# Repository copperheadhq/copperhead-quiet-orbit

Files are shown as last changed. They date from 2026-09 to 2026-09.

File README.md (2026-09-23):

# Quiet Orbit QO-R1

A USB-C powered desk ornament: four amber LEDs at the corners of a 40 mm square, each on its
own hardware-PWM channel of an ATtiny84A, fading independently on four phases. 57 × 57 mm,
two layers, no data, no PD, no radio, no battery, no controls.

> ## ⚠ This board has never been built
>
> No PCB has been fabricated from these files. Nothing has been powered on. The firmware has
> never been compiled, because no AVR toolchain was available where it was written, and it has
> never run on hardware. Every manufacturer part number in the BOM is marked **UNVERIFIED** by its own
> author, and at least one fitted part is known to be the wrong choice.
>
> The files pass ERC and DRC. That means the copper is consistent with the schematic and with
> a set of design rules. It is not evidence that the circuit works.
>
> **Do not order this board expecting a working lamp.** Order it to look at, to fork, or to
> fix.

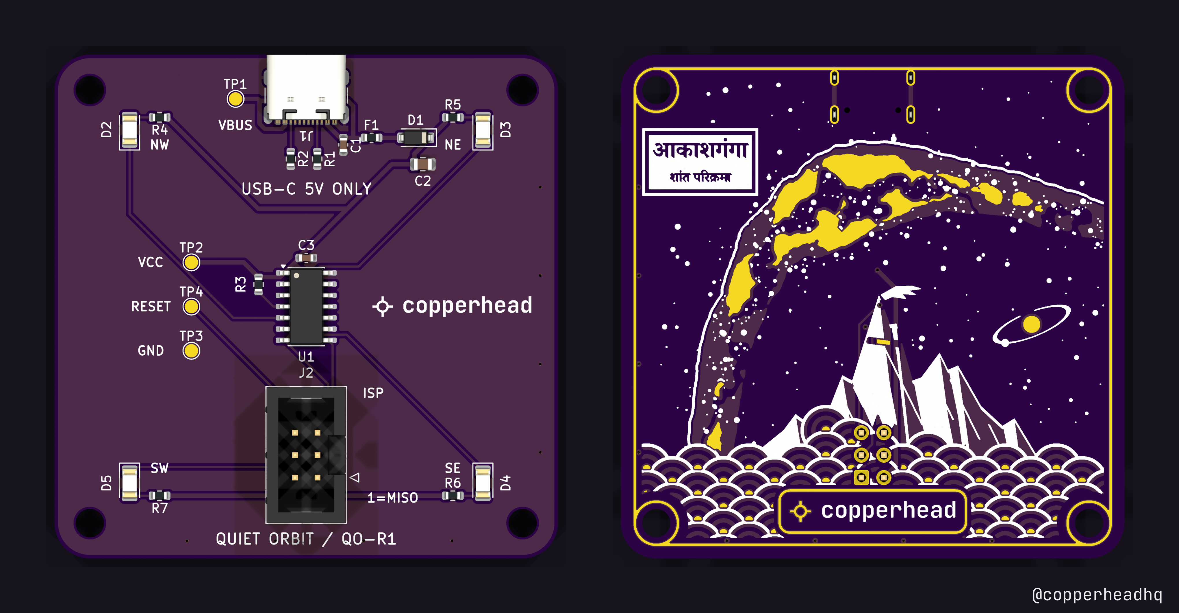
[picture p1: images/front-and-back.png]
The 57 mm board, front and back (a render, not a photograph)


Quick facts: [docs/QO-R1-summary.pdf](docs/QO-R1-summary.pdf). Everything: [docs/QO-R1-reference.pdf](docs/QO-R1-reference.pdf).

## Background

On 21 September 2026, Paras Chopra [posted](https://x.com/paraschopra/status/2101906787050115492)
that he had asked an AI model he calls Astra to design a piece of hardware for itself. It chose
four softly blinking lights powered by USB, and produced a PCB, a casing and an email to a
manufacturer.

The same day we gave that post to [copperhead](https://x.com/copperheadhq) as a brief and
[shared the result](https://x.com/animeshsingh38/status/2102001126682042727). This repository is
that build, with its source files. It is an independent design that started from the public post. No files, images or schematics
from the original project are used here.

## The circuit

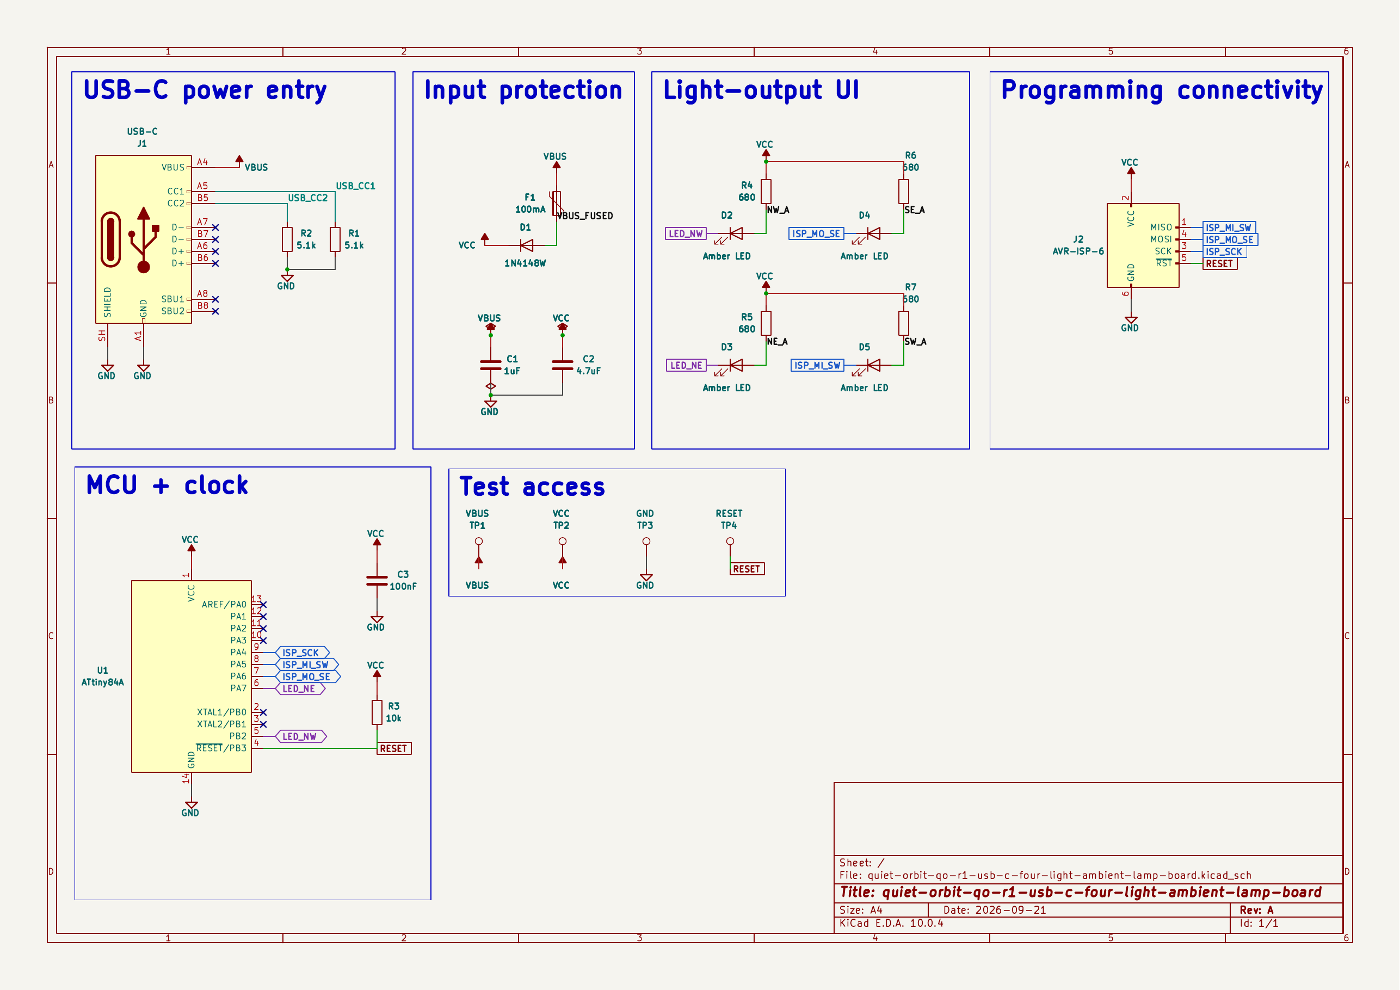
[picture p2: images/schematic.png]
Schematic


Full sheet as [PDF](docs/schematic.pdf) or [SVG](docs/schematic.svg). Source of truth is
`hardware/*.kicad_sch`. The exports are generated from it.

## Layout of this repository

```text
hardware/           KiCad 10 project: schematic, 57 × 57 mm board, design rules,
                    project footprint and symbol libraries
  variant-milkyway/ alternative back with Milky Way artwork in copper, mask and silk
firmware/           AVR-GCC, ATtiny84A, two 8-bit timers driving four PWM channels
docs/               summary and reference PDFs, specification, subsystems, pinout, BOM,
                    design decisions, changelog, and the schematic as PDF and SVG
fab/                gerbers, drill, BOM and CPL (read the warning in that folder)
images/             renders of the board, not photographs
3d/                 STEP, GLB and STL models, including one for an enclosure designer
LICENSES/           full text of the three licences below
```

## Building it

**Hardware.** Open `hardware/*.kicad_pro` in KiCad 10.0.4 or newer. The project carries its own
symbol cache and footprint libraries, so it opens standalone.

**Firmware.** Needs `avr-gcc` and `avr-libc`:

```bash
make -C firmware        # produces quiet-orbit-qo-r1.hex for attiny84 at F_CPU=8000000UL
```

This has never been run. If it does not compile, please send a patch.

Flash through J2 with any AVR ISP programmer. The ATtiny84A arrives blank and runs on its
internal 8 MHz RC oscillator. There is no crystal and no regulator. If your part ships with the
clock divided by 8, change that fuse; nothing else needs changing.

## Licence

Three licences, by file type:

| What | Licence |
|---|---|
| Hardware: everything under `hardware/`, `fab/` and `3d/` | **CERN-OHL-S-2.0** (strongly reciprocal) |
| Software: `firmware/` | **GPL-3.0-only** |
| Documentation and images: `docs/`, `images/`, `README.md` | **CC-BY-4.0** |

Full texts are in [`LICENSES/`](LICENSES/). In short: you may make, modify, sell and fabricate
this, and if you distribute a modified board or modified firmware you must publish your sources
under the same terms. See [`LICENSE`](LICENSE) for the per-directory statement.

**Trademarks are not licensed.** The copperhead word mark and the snake lockup that appear on
the silkscreen are trademarks; the licences above cover the design, not the marks. If you
fabricate a modified board, remove them from the silkscreen.

**No warranty.** This is an unbuilt, unverified design. CERN-OHL-S-2.0 sections 8 and 9 apply:
no warranty, no liability. If you fabricate it, that decision is yours.

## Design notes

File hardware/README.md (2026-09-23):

# Hardware

KiCad 10 project for the Quiet Orbit QO-R1. Open `*.kicad_pro`.

This board has never been fabricated. The series diode D1 (1N4148W) is the wrong part for the
power path; a 1 A Schottky in the same SOD-123 footprint is the better fit.

| File | What |
|---|---|
| `*.kicad_sch` | schematic |
| | *(readable exports: `docs/schematic.pdf`, `docs/schematic.svg`)* |
| `*.kicad_pcb` | 57 × 57 mm, 2 layers |
| `*.kicad_dru` | custom design rules, described below |
| `*.kicad_pro` | project settings, including the rule set used for DRC |
| `schematic.intent.json` | the machine-readable intent the schematic was generated from |
| `sym-lib-table`, `sym-lib-cache/` | project symbols, so the project opens standalone |
| `libs/footprints/` | project footprint libraries, from the KiCad standard set |
| `variant-milkyway/` | alternative back with copper artwork |

## Design rules

Our own conservative set, not any named fab's: clearance 0.2 mm, track 0.25 mm signal and 0.5 mm on
the power rails, via 0.65 / 0.3 mm, copper to edge 0.4 mm, hole clearance 0.25 mm, silk text at
least 1.0 mm. No KiCad severity is changed from default and there are no DRC exclusions.

One scoped rule is in the `.kicad_dru`: hole clearance 0.19 mm between J1 and itself. The
USB-C receptacle's stock land pattern puts its GND pads 0.194 mm from its own locating-peg
holes, which is four errors on any board using that footprint at the board-wide 0.25 mm. The
board-wide rule is untouched. A fab with a hard 0.2 mm NPTH-to-copper limit will query it.

Every two-pad part also carries a thin no-track rule area across its pad gap. This was added
after the autorouter put a track between the pads of an 0603. That passed DRC but is poor
practice.

## Geometry

57 × 57 mm. LED optical centres on a board-centred 40 mm square (NW, NE, SE, SW). Four M3
NPTH holes, each centre 4 mm from both adjacent edges. USB-C centred on one edge and flush
with it. All populated parts on the top side.

57 mm is close to the geometric floor for this brief: at 56.5 mm the LED and M3 courtyards are
0.13 mm apart, and at 56.0 mm they overlap. Going smaller means moving the mounting holes
inside the LED square or abandoning the 40 mm pitch.

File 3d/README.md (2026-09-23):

# 3D models

Exported with `kicad-cli` from the 57 mm board. Component bodies are generic KiCad library
models, not the exact manufacturer parts. Use them for fit, not for tolerance.

| File | For |
|---|---|
| `quiet-orbit-57mm.step` | full model: tracks, pads, zones, silkscreen and mask |
| `quiet-orbit-57mm-mechanical.step` | board and component bodies only. Give this one to an enclosure designer |
| `quiet-orbit-57mm.glb` | the full model for a web or Blender viewer |
| `quiet-orbit-57mm-board-only.stl` | bare outline with holes, for a fit-check print |

The board is designed against an 80 × 80 × 25 mm enclosure with four light windows over the
LED positions. Note the 0.47 mm gap between the LED and M3 hole courtyards at each corner: a
baffle or light pipe has to share that corner with a screw head.

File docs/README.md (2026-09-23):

# Documentation

The design documents, published as they were written alongside the schematic.

| File | What |
|---|---|
| `QO-R1-summary.pdf` | two-page summary: key figures, LED channels, BOM, checks before ordering |
| `QO-R1-reference.pdf` | full design reference: requirements, circuit, pinout, BOM, power budget, firmware, PCB, fab outputs, status |
| `SPEC.md` | the product specification, with normative requirements and every assumption marked |
| `SUBSYSTEMS.md` | power architecture, LED drive, MCU and programming |
| `PINOUT.md` | the ATtiny84A pin map, and the source of `firmware/pins.h` |
| `BOM.md` | bill of materials, with a rationale per line. Every part number is marked UNVERIFIED |
| `LAYOUT.md` | how the 57 mm board is laid out |
| `DECISIONS.md` | design decisions with reasons, in the order they were made |
| `CHANGELOG.md` | one entry per design stage |
| `schematic.pdf`, `schematic.svg` | the schematic sheet, exported from `hardware/*.kicad_sch` with `kicad-cli` 10.0.4, text stroke weight increased for print and projection. Regenerate rather than edit |

Two caveats on reading them:

- `DECISIONS.md` and `CHANGELOG.md` sometimes reference files that are not in this repository:
  an `outputs/` directory, an `openspec/` workspace and a first-draft 70 mm `LAYOUT.md`. The `LAYOUT.md` here
  is a replacement describing the board this repository actually contains.
- `DECISIONS.md` records the choices as made at the time, including some later found wrong.
  The choice of a 1N4148W as the reverse-blocking diode is one of them; fit a Schottky instead.

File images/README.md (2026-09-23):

# Images

These are renders, not photographs. No board has been made. They come from KiCad's raytracer
using generic 3D models from the standard library, not the exact manufacturer parts.

| Files | View |
|---|---|
| `01-top.png`, `02-bottom.png` | orthographic |
| `03-`, `04-` | perspective from the ISP side |
| `05-`, `06-` | perspective from the USB side |
| `07-back-iso.png` | underside |
| `08-closeup-usb-input.png` | the input chain: connector, bulk cap, fuse, diode |
| `09-closeup-mcu-isp.png` | MCU, bypass, RESET pull-up and ISP header |
| `front.png`, `back.png`, `back-angle.png` | the Milky Way variant, purple mask and ENIG |
| `bare-top.png`, `bare-bottom.png` | the bare board with no parts fitted: pads, tracks, silkscreen and mask as a fab would deliver it |
| `bare-milkyway-back.png` | the Milky Way variant's back, bare, in purple mask with ENIG gold |
| `schematic.png` | the schematic sheet as KiCad plots it, with border, zone markers and title block. Same sheet as `docs/schematic.pdf` |

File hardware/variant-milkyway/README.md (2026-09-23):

# Milky Way variant

The same circuit and the same placement, with the back of the board turned into a picture: the
Milky Way arching over a mountain, built from three finishes a fab can produce:
copper with a mask opening (gold, on ENIG), copper under mask (purple) and bare laminate
(dark purple), plus silkscreen for the stars.

`*.kicad_pcb` and `*.kicad_pro` here replace the two files of the same name one directory up.
Everything else in the project (schematic, rules, libraries) is shared.

Differences from the plain board:

- 4 mm rounded corners.
- No back GND pour. The artwork needs bare laminate for its dark sky. The artwork's gold
  frame, including eyelets around the M3 holes, becomes the GND ring instead, because the
  USB-C receptacle reaches ground partly through its shell stakes and that pour.
- The artwork's copper is floating polygons with no net, cut back from every pad, via, track
  and hole. Large areas of intentionally floating exposed copper will look like an error to a
  fab's reviewer. Say so on the order.
- Requires ENIG, not HASL. HASL would tin the exposed copper and the picture would be lost.

DRC at all severities with schematic parity after the artwork was applied: 0 / 0 / 0.

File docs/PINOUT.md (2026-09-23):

# Quiet Orbit QO-R1 Pinout

This table is authoritative for schematic-stage signal assignment. Every unused signal pin is explicitly marked NC in `schematic.intent.json`.

| Ref | Pin | Net | Function | Rationale |
|---|---:|---|---|---|
| U1 | 1 | VCC | Protected 5 V supply | Direct protected-VBUS architecture requires no regulator. |
| U1 | 2 | NC | PB0 / XTAL1 unused | Internal 8 MHz RC clock eliminates an external clock connection. |
| U1 | 3 | NC | PB1 / XTAL2 unused | Internal 8 MHz RC clock eliminates an external clock connection. |
| U1 | 4 | RESET | Active-low reset / PB3 | Dedicated reset supports reliable AVR ISP. |
| U1 | 5 | LED_NW | PB2 / OC0A hardware PWM | Dedicated PWM sinks the NW LED channel. |
| U1 | 6 | LED_NE | PA7 / OC0B hardware PWM | Dedicated PWM sinks the NE LED channel. |
| U1 | 7 | ISP_MO_SE | PA6 / MOSI / OC1A hardware PWM | MOSI is shared with the SE LED through its 680 ohm fitted load, which limits loading during ISP. |
| U1 | 8 | ISP_MI_SW | PA5 / MISO / OC1B hardware PWM | MISO is shared with the SW LED through its 680 ohm fitted load, which limits loading during ISP. |
| U1 | 9 | ISP_SCK | PA4 / SCK | Dedicated ISP clock avoids an LED load on SCK. |
| U1 | 10 | NC | PA3 unused | No additional function is required. |
| U1 | 11 | NC | PA2 unused | No additional function is required. |
| U1 | 12 | NC | PA1 unused | No additional function is required. |
| U1 | 13 | NC | PA0 / AREF unused | ADC and external reference are outside scope. |
| U1 | 14 | GND | Ground | MCU supply return. |
| J2 | 1 | ISP_MI_SW | AVR ISP MISO | Shared only through a resistor-limited LED load. |
| J2 | 2 | VCC | Programmer voltage sense | Sense-only; the product must be powered from USB. |
| J2 | 3 | ISP_SCK | AVR ISP SCK | Dedicated clock connection. |
| J2 | 4 | ISP_MO_SE | AVR ISP MOSI | Shared only through a resistor-limited LED load. |
| J2 | 5 | RESET | AVR ISP reset | Connected to U1 reset and the 10 kOhm pull-up. |
| J2 | 6 | GND | Ground | Programmer reference return. |
| J1 | A4,A9,B4,B9 | VBUS | USB 5 V input | All receptacle VBUS contacts are joined. |
| J1 | A5 | USB_CC1 | CC1 sink detect | Independent 5.1 kOhm pull-down through R1. |
| J1 | B5 | USB_CC2 | CC2 sink detect | Independent 5.1 kOhm pull-down through R2. |
| J1 | A1,A12,B1,B12,SH | GND | Ground and shield | Shell is tied to board ground in this revision. |
| J1 | A6,A7,A8,B6,B7,B8 | NC | USB data and SBU unused | Power-only product; data and alternate modes are intentionally absent. |

## LED channel mapping

| Position | LED | Resistor | MCU pin | PWM output | Shared ISP signal |
|---|---|---|---:|---|---|
| NW | D2 | R4 | U1.5 | OC0A | None |
| NE | D3 | R5 | U1.6 | OC0B | None |
| SE | D4 | R6 | U1.7 | OC1A | MOSI |
| SW | D5 | R7 | U1.8 | OC1B | MISO |

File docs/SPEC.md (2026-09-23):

# Quiet Orbit QO-R1 Product Specification

## Product

Quiet Orbit QO-R1 is a USB-C-powered desk ornament whose four warm-amber light windows form a 2 × 2 grid and fade independently on four phases. It has no USB data, Power Delivery, radio, battery, buttons, or other user controls. Firmware is programmed once at the factory through AVR ISP.

Requirement words **MUST**, **SHALL**, **SHOULD**, and **MAY** are normative. Items marked **ASSUMED** are defaults introduced because the brief does not specify them and may be revised during design review. Each assumption includes its rationale.

## Top-level budgets and constraints

- Input supply: nominal USB VBUS, 5 V only; the circuit SHALL tolerate the normal USB 5 V supply range. No voltage above 5 V may be requested through PD. (QO-001) Rationale: the product is a fixed 5 V USB sink.
- USB input current: total steady-state current from USB SHALL remain strictly below 100 mA in every operating mode. (QO-010) Rationale: preserves the stated source-current ceiling with any compliant port or charger.
- LED count and optical band: exactly four discrete amber LEDs, each 590–605 nm. (QO-004) Rationale: establishes the intended four-window warm-amber appearance.
- LED full-brightness current: each LED SHALL draw 2–5 mA, inclusive; the four LEDs therefore consume at most 20 mA combined. (QO-004) Rationale: meets the brightness requirement while leaving substantial input-current margin.
- LED geometry: LED optical centres SHALL occupy the corners of a 40 mm × 40 mm square centred on the board. (QO-005) Rationale: fixes alignment with the four enclosure windows.
- Board envelope: the finished PCB SHALL be square and no larger than 72 mm × 72 mm. (QO-008) Rationale: fits the specified 80 mm × 80 mm × 25 mm enclosure.
- Mounting: exactly four M3 non-plated mounting holes, one near each corner, with each hole centre 4 mm from both adjacent board edges. (QO-008) Rationale: matches the stated enclosure mounting geometry.
- Stack-up: two copper layers and 1.6 mm finished thickness using standard fabrication rules. (QO-010) Rationale: meets the cost and manufacturability target.
- Programming connector: 2 × 3 positions on 2.54 mm pitch. (QO-006) Rationale: maintains compatibility with standard AVR ISP cables.
- RESET pull-up: 10 kΩ to protected VCC. (QO-006) Rationale: provides a defined run state while allowing ISP assertion.
- USB-C CC termination: CC1 and CC2 SHALL each have an independent 5.1 kΩ pull-down to GND. (QO-001) Rationale: advertises a sink correctly for both plug orientations and supports C-to-C cables.
- MCU clock: the ATtiny84A SHALL use its internal 8 MHz RC oscillator. (QO-003) Rationale: eliminates the crystal and its load components.

## Functional requirements

### QO-001: USB-C power input

The board SHALL use a USB-C receptacle as a 5 V sink only. CC1 and CC2 SHALL each have their own 5.1 kΩ Rd termination. USB D+ and D− SHALL not be routed or connected, and the design SHALL contain no PD controller or other negotiation circuitry. The receptacle SHALL be centred on one board edge and mechanically flush with that edge.

### QO-002: Input protection and filtering

A resettable fuse SHALL be sized for the load. Reverse-current protection SHALL prevent a programmer or any header voltage from back-feeding the USB VBUS pin. Bulk and local bypass capacitance SHALL support USB hot-plugging and normal transient load steps.

- **ASSUMED:** Use a PTC with 100 mA nominal hold current and at least 200 mA trip current at 25 °C, subject to final tolerance and thermal derating review. Rationale: it passes the allowed load while providing useful fault discrimination.
- **ASSUMED:** Limit receptacle-side input capacitance to 10 µF nominal and place at least 1 µF bulk capacitance after the fuse/protection element. Rationale: provides transient energy without excessive hot-plug inrush.
- **ASSUMED:** Provide one 100 nF ceramic decoupling capacitor directly at the MCU supply pins. Rationale: this is the conventional minimum local high-frequency bypass for the ATtiny84A.
- **ASSUMED:** Reverse leakage from protected VCC toward VBUS SHALL be no more than 10 µA at room temperature when VBUS is unpowered and protected VCC is driven to 5 V. Rationale: makes accidental USB-port back-power negligible and objectively testable.

### QO-003: Controller

The MCU SHALL be a Microchip ATtiny84A in SOIC-14, powered directly from protected 5 V. It SHALL use its internal 8 MHz RC oscillator. No crystal, external oscillator, or regulator SHALL be fitted. MCU pin assignment SHALL be checked against reset, ISP, and alternate-function tables before schematic capture.

### QO-004: Lights and drive

The board SHALL contain four discrete 590–605 nm amber LEDs in 1206 or a similarly hand-reworkable package. Each LED SHALL have its own series resistor and its own MCU pin with a hardware PWM output, permitting four simultaneous independent fades. Full-brightness current SHALL be 2–5 mA per LED.

- **ASSUMED:** Target 4 mA nominal per LED at 5 V; the final resistor SHALL be calculated from the selected LED forward-voltage limits so the full tolerance range remains within 2–5 mA. Rationale: centres brightness within the allowed range and preserves wide current margin.
- ISP-shared LED pins MAY be used only if the fitted LED/resistor networks do not prevent reliable programming. Rationale: pin sharing is explicitly permitted but programming remains mandatory.

### QO-005: LED placement

As viewed from the component side, the four LEDs SHALL be named NW, NE, SE, and SW and placed at the corners of a board-centred 40 mm × 40 mm square. Their optical centres, rather than footprint origins, govern placement.

### QO-006: Factory programming

Provide a standard 2 × 3, 2.54 mm AVR ISP header with pin 1 identified on silkscreen. RESET SHALL have a 10 kΩ pull-up. The product SHALL be powered from USB while programming; the ISP VCC pin SHALL be a voltage-sense connection only and SHALL not be a permitted power input. Programming SHALL work with all LEDs and resistors fitted.

### QO-007: Test access

Provide separately accessible test points for VBUS, protected VCC, GND, and RESET. Each SHALL be labelled on silkscreen with that exact net name.

- **ASSUMED:** Each test point SHALL expose a probeable pad at least 1.0 mm in its smallest dimension with at least 0.5 mm unobstructed clearance around it. Rationale: supports reliable manual factory probing without requiring a custom fixture.

### QO-008: Mechanical construction

The PCB SHALL be square and no larger than 72 mm × 72 mm. It SHALL fit an 80 mm × 80 mm × 25 mm enclosure. Four M3 non-plated mounting holes SHALL be provided, one per corner, with hole centres 4 mm from each adjacent edge. The USB-C receptacle SHALL be centred on one edge and flush with that edge. All components SHALL be on the top side.

- **ASSUMED:** Use a 70 mm × 70 mm board outline. Rationale: provides 1 mm dimensional margin on every side relative to the maximum envelope while retaining useful routing area.
- **ASSUMED:** Use 3.2 mm finished drill diameter for the M3 clearance holes. Rationale: this is a common close-clearance size for M3 hardware.

### QO-009: Marking

Top silkscreen SHALL include “QUIET ORBIT / QO-R1” and “USB-C 5V ONLY” near the receptacle. It SHALL also identify ISP pin 1 and the four required test points.

### QO-010: Fabrication, assembly, and sourcing

The design SHALL use a two-layer, 1.6 mm PCB compatible with standard fabrication rules. All parts SHALL be orderable from major distributors at design release. SMT parts SHALL be factory-assemblable on the top side; the ISP header MAY be through-hole. Total USB current SHALL remain below 100 mA.

- **ASSUMED:** Standard design-rule minima are 0.20 mm copper track width, 0.20 mm copper clearance, 0.30 mm finished via drill, and 0.60 mm via diameter unless the selected fabricator permits no better. Rationale: conservative values are broadly supported by low-cost PCB fabs.
- **ASSUMED:** Every production BOM item SHALL have at least one orderable manufacturer part number from a major distributor and SHOULD have a form-fit-function alternative where practical. Rationale: makes the sourcing requirement reviewable and reduces lifecycle risk.

## Power budget

Worst-case steady-state allocation against the strict <100 mA USB limit:

- Four LEDs: 20 mA maximum total (4 × 5 mA).
- **ASSUMED:** MCU and all non-LED circuitry: maximum 20 mA combined in normal operation. Rationale: this comfortably covers the ATtiny84A at 8 MHz plus passive leakage and leaves explicit margin.
- **ASSUMED:** Design verification ceiling: 40 mA expected maximum steady-state load, leaving more than 60 mA margin to the required limit. Rationale: a 2.5× margin accommodates tolerance and abnormal firmware states while keeping fuse selection practical.

The schematic BOM and component limits SHALL be checked against both the 40 mA expected ceiling and the absolute requirement of less than 100 mA.

## Scope exclusions

Enclosure CAD, firmware implementation, USB data, USB Power Delivery, wireless connectivity, batteries, user controls, and compliance testing are outside this project. These exclusions do not waive the electrical and mechanical interface requirements above.

## Acceptance criteria

The design is acceptable only when schematic ERC and PCB DRC pass; all four LED pins are verified as hardware-PWM-capable; AVR ISP operation is compatible with the fitted LED networks; the current and protection budgets are demonstrated from component limits; LED and mechanical coordinates match this specification; all required markings and test points are present; and BOM sourcing plus top-side assembly constraints are satisfied.

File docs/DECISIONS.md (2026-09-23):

- 2026-09-21 [run 2026-09-21T08-38-52-754Z] Do not seed openspec/specs capability requirements in this stage. | why: No openspec workspace existed when the repository was inspected; the workflow-created change proposal does not retroactively constitute a pre-existing workspace. | affects: openspec/specs, openspec/changes/seed-qo-r1-spec
- 2026-09-21 [run 2026-09-21T08-38-52-754Z] Adopt a 70 mm square PCB as the assumed starting outline. | why: It retains useful routing area while providing 1 mm margin per side against the 72 mm maximum. | affects: docs/SPEC.md, PCB outline, LED and mounting-hole coordinates
- 2026-09-21 [run 2026-09-21T08-38-52-754Z] Use explicit assumed protection, capacitance, leakage, and 40 mA expected-load targets for initial design. | why: The brief requires protection and appropriate hot-plug capacitance but does not quantify them; measurable defaults are needed for schematic selection and review. | affects: docs/SPEC.md, input protection, fuse, capacitors, power verification
- 2026-09-21 [run 2026-09-21T08-52-42-409Z] Partition the steady-state architecture into a maximum 20 mA LED load and a maximum 20 mA MCU-plus-non-LED load, for a 40 mA expected ceiling. | why: This directly preserves the SPEC.md allocations and leaves more than 60 mA margin to the strict below-100 mA USB limit. | affects: docs/SUBSYSTEMS.md, power architecture, LED drive, MCU and protection selection
- 2026-09-21 [run 2026-09-21T08-52-42-409Z] Defer the ATtiny84A pin map until hardware-PWM outputs, RESET, AVR ISP signals, alternate functions, and fitted LED loads are checked together. | why: A premature pin assignment could satisfy PWM superficially while breaking reset or reliable factory programming. | affects: docs/SUBSYSTEMS.md, future schematic pin allocation, AVR ISP, four LED channels
- 2026-09-21 [run 2026-09-21T08-52-42-409Z] Use a direct protected-5-V architecture with no regulator, USB data circuit, PD controller, crystal, or user-control subsystem. | why: These omissions are intentional because the specified ATtiny84A operates from protected USB VBUS and the excluded functions would add unnecessary parts and current. | affects: docs/SUBSYSTEMS.md, future schematic, BOM, power budget
- 2026-09-21 [run 2026-09-21T08-54-11-562Z] Use a series 1N4148W silicon diode, rather than a Schottky diode, as the provisional reverse-current blocking element. | why: Its low reverse leakage is compatible with the 10 µA back-feed limit while its forward drop still leaves adequate voltage for the 5 V ATtiny84A and resistor-limited LEDs. | affects: D1, protected VCC, LED resistor calculations, reverse-current verification
- 2026-09-21 [run 2026-09-21T08-54-11-562Z] Capture the SOIC-14 ATTINY84A-SSUR using the installed 14-pin ATtiny84A-P symbol and the explicit SOIC-14 footprint. | why: The installed symbol's authoritative pin list matches the 14-pin package numbering, while the BOM MPN and footprint explicitly control the required SOIC package. | affects: U1, stage-4 symbol resolution, SOIC-14 footprint, ISP and PWM pin mapping
- 2026-09-21 [run 2026-09-21T08-54-11-562Z] Select individual 680 ohm 1% resistors for the four provisional amber LED channels. | why: Using the documented provisional voltage bounds gives about 2.26–4.38 mA per channel, within the required 2–5 mA range and below the 20 mA combined LED budget. | affects: R4-R7, D2-D5, LED current and USB power budgets
- 2026-09-21 [run 2026-09-21T08-58-02-010Z] Assign the four LED channels to U1 PB2/OC0A, PA7/OC0B, PA6/OC1A, and PA5/OC1B, sharing the latter two with AVR ISP MOSI and MISO through the fitted 680 ohm LED networks. | why: These are the ATtiny84A's four hardware-PWM outputs, and the resistor-limited LED loads preserve factory programming while PA4 remains a dedicated SCK connection. | affects: U1 pins 5-9, D2-D5, R4-R7, J2, docs/PINOUT.md, schematic.intent.json
- 2026-09-21 [run 2026-09-21T08-58-02-010Z] Tie the USB-C receptacle shield pin to board GND and leave all USB data and SBU pins explicitly unconnected. | why: The product is a power-only 5 V sink with no USB data or alternate-mode function; the grounded shell provides a defined shield connection. | affects: J1, GND, USB D+/D-/SBU pins, docs/PINOUT.md, schematic.intent.json
- 2026-09-21 [run 2026-09-21T08-58-02-010Z] Accept the deterministic drafter's synthesized copperhead_power aliases for GND, VBUS, VCC, and PWR_FLAG in this generated schematic. | why: All nine design symbols and their real pins verify, while these four findings are engine-owned local aliases for standard power symbols and cannot be changed through the intent IR without violating the generated-sheet workflow; ERC is clean. | affects: generated power symbols, verify_symbols report, quiet-orbit-qo-r1-usb-c-four-light-ambient-lamp-board.kicad_sch
- 2026-09-21 [run 2026-09-21T09-10-27-200Z] Use a coordinate-driven 70 mm first-draft placement with the USB-C centred on the north edge, LEDs on the exact 40 mm grid, input protection directly behind the receptacle, and MCU bypass directly beside U1; leave all noncritical remaining connections as an explicitly documented ratsnest. | why: This captures the mechanical and critical-current-path constraints in inspectable geometry while keeping provisional routing visibly distinct from release-ready specialist work. | affects: PCB outline, J1, C1, F1, D1, C2, U1, C3, D2-D5, mounting holes, docs/LAYOUT.md
- 2026-09-21 [run 2026-09-21T09-17-15-484Z] Generate the Stage 6 output package directly from the current KiCad board and schematic, and consolidate identical BOM MPNs into one ordering row with a comma-separated refdes field and quantity. | why: Source-derived exports and grouped MPN rows keep fabrication geometry and purchasing quantities traceable while preserving every existing UNVERIFIED and DNP designation. | affects: outputs/ Gerbers, drill, DXF, STEP, SVG renders, outputs/BOM.csv, docs/CHANGELOG.md
- 2026-09-21 [run 2026-09-21T09-18-28-371Z] Use AVR-GCC with two 8-bit fast-PWM timer blocks and keep all board-pin definitions exclusively in firmware/pins.h generated from docs/PINOUT.md. | why: The ATtiny84A exposes the four reviewed hardware-PWM outputs across Timer 0 and Timer 1, and a single generated mapping prevents firmware/schematic pin drift while preserving RESET and ISP roles. | affects: firmware/pins.h, firmware/led_pwm.c, firmware/main.c, firmware/Makefile, firmware/DEVPLAN.md
- 2026-09-21 [run 2026-09-21T09-20-46-702Z] Prohibit prototype fabrication from the current draft outputs and use gated bare-board, two-unit hand-assembly, and representative assembly-pilot orders only after routing, footprint, sourcing, and full-release DRC closure. | why: The current layout intentionally retains unrouted nets, provisional footprint geometry, and deferred DRC classes, so staged release gates minimize scrap while preserving measurable electrical and mechanical validation. | affects: docs/DEVPLAN.md, outputs/, PCB release review, prototype purchasing and bring-up

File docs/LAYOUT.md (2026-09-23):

# Layout

The board in `hardware/` is 57 × 57 mm, two layers, all parts on the top side.

## Geometry

LED optical centres sit on a board-centred 40 mm square at (8.5, 8.5), (48.5, 8.5), (48.5,
48.5) and (8.5, 48.5) mm (NW, NE, SE, SW, labelled on the silkscreen). The four M3 NPTH holes
are 4 mm from both adjacent edges. The USB-C receptacle is centred on one edge, flush with it.

The four LEDs are vertical with the cathode facing the horizontal centre line and the current-
limiting resistor beside the anode, each anode link a single straight 2.58 mm segment. That
orientation was chosen by generating and measuring three variants: it took the LED-drive nets
from 159 mm and 3 vias to 142 mm and none.

Power-entry parts are grouped directly behind the receptacle, the bulk capacitor 2.7 mm from
the nearest VBUS pad. The MCU bypass capacitor is 2.4 mm from the MCU supply pin and the RESET
pull-up 3.4 mm from RESET.

The MCU and ISP header orientations were searched rather than chosen: all eight combinations
were generated and routed, and the one with the fewest signal vias and the least back-layer
copper was kept: 2 vias and 32 mm, against 3 and 53 mm for the obvious orientation.

Result: 89 track segments, 376.5 mm of track, 24 vias of which 21 are ground stitching.

## How small it can go

With the LEDs on a 40 mm square and the M3 holes 4 mm from each edge, the limit is geometric.
The LED courtyard meets the mounting-hole courtyard on the corner diagonal:

| Edge | LED-to-hole courtyard gap | |
|---|---|---|
| 56.0 mm | −0.22 mm | overlaps; 6 courtyard errors |
| 56.5 mm | +0.13 mm | the floor |
| **57.0 mm** | **+0.47 mm** | the board |
| 58.0 mm | +1.17 mm | |

57 mm is 32.5 cm² against 49 cm² for a 70 mm board, 34 % less area. Going below it means
changing an assumption rather than the layout: mounting holes inside the LED square gives
roughly 46 mm, and dropping the 40 mm LED pitch as well roughly 31 mm, at which point the
shrouded ISP header (38 % of all courtyard area) is the thing to change first. Both figures
are estimates and were never laid out.

Note that under 70 mm a single board no longer qualifies for the assembly tier that includes
factory programming at the fab this was costed against, without panelising. Flashing through
the ISP header is the fallback.

## Things a reviewer should question

- The ISP header's ground pin and the SMD ground pads connect solid to the pours, with no
  thermal relief, because the ISP tracks leave no room for spokes. That through-hole pin is harder to
  hand-solder or rework as a result.
- The USB-C receptacle is SMT-only on a board edge, with no mechanical stakes beyond its own
  shell tabs.
- The "USB-C 5V ONLY" silkscreen has tracks under it. Under mask, legible, cosmetic.
- Test points are in the BOM because the schematic puts them there, and marked DNP in
  `BOM.md`. One of the two is wrong.
- Routing is autorouted. The longest nets are the ISP data line at 55 mm and VCC at 117 mm.
  There are no fiducials, and no fab has run DFM on it.

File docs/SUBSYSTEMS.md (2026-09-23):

# Quiet Orbit QO-R1 Subsystem Architecture

## System block diagram in prose

A USB-C receptacle accepts nominal 5 V VBUS as a power-only sink. Independent 5.1 kΩ resistors terminate CC1 and CC2 to GND; D+ and D− remain unconnected and no Power Delivery controller is present. VBUS passes through a load-sized resettable fuse and a reverse-current blocking element to create protected VCC. Receptacle-side capacitance is limited to 10 µF nominal, while protected VCC has at least 1 µF of bulk capacitance and a 100 nF ceramic capacitor at the MCU supply pins. Protected VCC powers an ATtiny84A and four resistor-limited amber LED channels. The MCU runs from its internal 8 MHz RC oscillator and independently modulates the four LEDs using four hardware-PWM-capable outputs. A 2 × 3 AVR ISP header connects programming signals, RESET, GND, and a protected-VCC sense connection; it is not a permitted power input. Test points expose VBUS, protected VCC, GND, and RESET. All circuitry is placed on the top side of a two-layer, 1.6 mm PCB within the defined mechanical envelope.

The steady-state architecture allocates at most 20 mA to the four LEDs and at most 20 mA to the MCU and all other non-LED circuitry. The expected design ceiling is therefore 40 mA, with more than 60 mA margin to the strict requirement that USB input current remain below 100 mA in every operating mode. Rationale: a simple direct-5-V architecture meets the product function without a regulator, USB data circuitry, or other avoidable loads.

## USB-C power entry

The connector is a USB-C receptacle configured only as a 5 V sink. CC1 and CC2 each receive their own 5.1 kΩ pull-down to GND so either plug orientation is detected correctly. D+ and D− are intentionally left unconnected, and neither a PD controller nor any higher-voltage negotiation circuitry is included. Rationale: the product needs power only and is constrained to nominal 5 V VBUS.

The receptacle is centred on one board edge and mechanically flush with that edge. The top silkscreen near it reads “USB-C 5V ONLY.” Rationale: this satisfies the enclosure interface and makes the allowed supply unmistakable.

## Input protection

VBUS first passes through a resettable PTC with a nominal 100 mA hold rating and at least 200 mA trip rating at 25 °C, subject to tolerance and thermal-derating review. A series reverse-current blocking element then generates protected VCC and must limit leakage back toward an unpowered VBUS pin to no more than 10 µA at room temperature when protected VCC is driven to 5 V. Rationale: the fuse provides fault discrimination while the blocking element prevents a programmer or sensed header voltage from back-powering the USB port.

Total nominal capacitance directly presented at the receptacle remains no greater than 10 µF. At least 1 µF of bulk capacitance is placed after the protection path, and a separate 100 nF ceramic capacitor is placed directly at the MCU supply pins. Rationale: this balances USB hot-plug inrush with local transient support and high-frequency decoupling.

Final component selection must demonstrate operation across the normal USB 5 V range, keep all protection and passive leakage inside the 20 mA non-LED allocation, satisfy the 10 µA reverse-leakage limit, and be orderable from a major distributor. Rationale: nominal function alone is insufficient unless worst-case electrical limits and sourcing also close.

## MCU + clock

The controller is a Microchip ATtiny84A in SOIC-14, powered directly from protected VCC with no regulator. It uses the internal 8 MHz RC oscillator, so no crystal, resonator, or oscillator load components are fitted. RESET is pulled up to protected VCC with 10 kΩ. Rationale: the specified MCU and internal clock provide the required control with minimal parts and current.

Four distinct MCU outputs must each provide hardware PWM for the four simultaneous independent fades. The final pin map is deliberately deferred until the ATtiny84A reset, ISP, timer-output, alternate-function, and strapping tables have been checked together. ISP-shared outputs may be used only after showing that the fitted LED and resistor loads do not prevent reliable programming. Rationale: this prevents an apparently convenient assignment from breaking PWM or factory programming.

The MCU plus protection and all other non-LED circuitry must remain at or below the assumed 20 mA normal-operation allocation. Rationale: preserving this allocation keeps the complete expected steady-state load at or below 40 mA.

## Light-output user interface

The only user interface is four discrete warm-amber LEDs named NW, NE, SE, and SW as viewed from the component side. Each LED has a dominant wavelength from 590 nm through 605 nm, uses a 1206 or similarly hand-reworkable package, and has its own series resistor and dedicated hardware-PWM drive. Rationale: independent channels create the four-phase fade effect while retaining factory reworkability.

Each channel targets 4 mA nominal at 5 V and must remain within 2–5 mA at full brightness over the selected LED forward-voltage and resistor tolerances. The four channels together must never exceed 20 mA. Final resistor values are therefore selected only after the production LED’s forward-voltage limits are known. Rationale: calculating from tolerance limits protects both the optical requirement and the power budget.

The four optical centres occupy the corners of a 40 mm × 40 mm square centred on the PCB. Rationale: optical centres, rather than footprint origins, must align with the enclosure windows. There are intentionally no buttons, display, audio, radio, or other user controls. Rationale: those functions are outside product scope and would add load and complexity.

## Programming connectivity

Factory programming uses a standard 2 × 3 position, 2.54 mm AVR ISP header with pin 1 identified on top silkscreen. The header carries the required AVR ISP signals, RESET, GND, and protected VCC sense. The product is powered from USB while programming; the ISP VCC contact is voltage sense only and is not an allowed power input. Rationale: this maintains standard tool compatibility without creating a back-power path.

RESET retains its 10 kΩ pull-up during programming. Any LED channels sharing ISP signals must use resistor-limited loads proven compatible with the programmer when all production parts are fitted. Rationale: factory programming is an acceptance requirement, not an optional debug feature.

## Test access

Separate test points expose the exact nets VBUS, protected VCC, GND, and RESET, and top silkscreen labels each with that exact net name. Each test point provides a probeable pad at least 1.0 mm in its smallest dimension with at least 0.5 mm unobstructed clearance around it. Rationale: these nodes permit direct verification of input power, protected power, reference ground, reset behaviour, and reverse isolation using manual probes.

## PCB and mechanical interface

The architecture assumes a 70 mm × 70 mm square PCB, remaining within the absolute 72 mm × 72 mm maximum and the 80 mm × 80 mm × 25 mm enclosure. It uses two copper layers, 1.6 mm finished thickness, minimum 0.20 mm track width, minimum 0.20 mm copper clearance, minimum 0.30 mm finished via drill, and minimum 0.60 mm via diameter. Rationale: these conservative rules preserve broad low-cost fabrication compatibility.

Exactly four M3 non-plated mounting holes use 3.2 mm finished drills. Each hole centre is 4 mm from both adjacent board edges, and the surrounding keepout must preserve mechanical clearance. All components are on the top side. Rationale: this matches the enclosure hardware and factory-assembly constraint.

Top silkscreen includes “QUIET ORBIT / QO-R1,” “USB-C 5V ONLY,” ISP pin 1 identification, and the four required test-point net names. Rationale: these markings support product identity, safe power connection, programming, and test.

## Budget and verification closure

The four LEDs consume no more than 20 mA combined, and the MCU plus every protection, termination, and leakage path consumes no more than 20 mA in normal operation. Thus the expected maximum steady-state load is 40 mA, and every operating mode must remain strictly below 100 mA from USB. Rationale: these nested limits retain explicit margin and guide component selection before schematic capture.

Schematic capture must verify the real ATtiny84A pin functions, four hardware-PWM outputs, ISP compatibility, component quiescent and leakage currents, LED current tolerance, reverse leakage, and capacitor placement. PCB implementation must verify connector alignment, LED optical-centre coordinates, mounting-hole geometry and keepouts, top-side assembly, stack-up, design rules, markings, and test-point access. ERC and PCB DRC must pass before design acceptance. Rationale: architecture values become complete only when traced into implementation and verified against the source files.

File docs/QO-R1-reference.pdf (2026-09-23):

TECHNICAL REPORT 21 SEPTEMBER 2026

# Quiet Orbit QO-R1: Design Reference

copperhead

https://github.com/copperheadhq/copperhead-quiet-orbit

A USB-C powered four-LED ambient lamp board, 57×57 mm

Abstract

Quiet Orbit QO-R1 is a desk ornament board: four warm-amber LEDs at the corners of a 40 mm square, each driven by its own hardware PWM output of an ATtiny84A and fading a quarter cycle apart, powered from USB-C at 5 V. The board is 57×57 mm, two layers, with all parts on the top side. This report describes the requirements, circuit, pin assignments, bill of materials, power budget, firmware, PCB, fabrication outputs and verification status of the design as committed. The schematic passes ERC and the board passes DRC with no exclusions. No board has been fabricated, the firmware has not been compiled, and no part has been checked against a current datasheet; one fitted part (D1) is known to be the wrong choice. Where this report and the source files disagree, the source files are correct.

Status: not built, not tested.
- No board has been fabricated. Nothing has been powered on.
- The firmware has never been compiled, because no AVR toolchain was available where it was written.
- Every manufacturer part number is unverified.
- D1 (1N4148W) is the wrong part for the power path. Fit a 1 A Schottky (B5819W or 1N5819HW class) in the same SOD-123 footprint.
- ERC and DRC pass. That shows the files agree with each other and with the design rules. It does not show that the circuit works.

Contents

1 Product | 2
2 Requirements | 2
3 Circuit | 3
4 Pin assignments | 4
5 Bill of materials | 4
6 Power budget | 5
7 Firmware | 5
8 PCB | 6
9 Milky Way variant | 7
10 Fabrication outputs | 7
11 Verification status | 8
12 Open items | 8
13 Licence | 9
A Renders | 10
B Schematic | 12

### 1 Product

A desk ornament powered from USB-C. Four warm-amber LEDs sit at the corners of a 40 mm square and fade independently, each a quarter cycle behind the last. The board has no USB data, no Power Delivery, no radio, no battery and no user controls. The firmware is written once through an AVR ISP header.

Board | 57×57 mm, square, 2 copper layers, 1.6 mm FR-4
Assembly | All parts on the top side; SMT except the ISP header
Enclosure | 80×80×25 mm with four light windows over the LEDs
Supply | USB VBUS, 5 V only
Controller | Microchip ATtiny84A, SOIC-14, internal 8 MHz RC oscillator
Outputs | 4 amber LEDs, 590 to 605 nm, each on its own hardware PWM channel

Table 1: Product summary.

Out of scope: enclosure CAD, USB data, USB Power Delivery, wireless, batteries, user controls and compliance testing.

### 2 Requirements

Requirement identifiers match docs/SPEC.md. Items marked assumed are defaults chosen where the brief gave no value.

QO-001 USB-C power input

- USB-C receptacle, 5 V sink only.
- CC1 and CC2 each have their own 5.1 kΩ pull-down to GND.
- D+ and D− are not connected. No PD controller or other negotiation circuit.
- Receptacle centred on one board edge and flush with it.

QO-002 Input protection and filtering

- Resettable fuse sized for the load. Assumed: 100 mA hold, at least 200 mA trip at 25◦C.
- Reverse-current protection so a programmer or header voltage cannot back-feed VBUS. Assumed: at most 10 µA reverse leakage at room temperature with VCC at 5 V and VBUS unpowered.
- Assumed: at most 10 µF nominal on the receptacle side; at least 1 µF bulk after the protection; 100 nF at the MCU supply pins.

QO-003 Controller

- ATtiny84A in SOIC-14, powered directly from protected 5 V.
- Internal 8 MHz RC oscillator. No crystal, no external oscillator, no regulator.

QO-004 Lights and drive

- Four discrete amber LEDs, 590 to 605 nm, 1206 or a similarly hand-reworkable package.
- Each LED has its own series resistor and its own MCU pin with a hardware PWM output, so all four can fade independently at the same time.
- Full-brightness current 2 to 5 mA per LED. Assumed: 4 mA nominal target.
- LED pins may be shared with ISP signals only if programming still works with all LEDs and resistors fitted.

QO-005 LED placement

- Viewed from the component side, the LEDs are NW, NE, SE and SW, at the corners of a 40×40 mm square centred on the board. Optical centres, not footprint origins, set the position.

QO-006 Factory programming

- Standard 2×3, 2.54 mm AVR ISP header with pin 1 marked on the silkscreen.

- 10 kΩ pull-up on RESET.
- The board is powered from USB while programming. The ISP VCC pin is a voltage-sense connection only.

QO-007 Test access

- Separate test points for VBUS, VCC, GND and RESET, each labelled with its net name. Assumed: pad at least 1.0 mm across with 0.5 mm clear around it.

QO-008 Mechanical

- Square board, no larger than 72×72 mm. The committed board is 57×57 mm; the specification’s original 70 mm starting outline was later reduced.
- Four M3 non-plated holes, one per corner, centres 4 mm from both adjacent edges. Assumed: 3.2 mm drill.
- All components on the top side.

QO-009 Marking

- Top silkscreen: “QUIET ORBIT / QO-R1”, “USB-C 5V ONLY” near the receptacle, ISP pin 1, and the four test point names.

QO-010 Fabrication, assembly and sourcing

- Two-layer, 1.6 mm board built to standard fab rules.
- Total USB current strictly below 100 mA in every mode.
- All parts orderable from major distributors; SMT parts assemblable on the top side; the ISP header may be through-hole.

### 3 Circuit

The full schematic is reproduced in Appendix B and in docs/schematic.pdf.

### 3.1 Power entry

J1 is a 16-pin USB-C receptacle (GCT USB4105). All four VBUS contacts are joined. R1 and R2 (5.1 kΩ) pull CC1 and CC2 to GND, so a source sees a sink in either plug orientation and supplies default 5 V. D+, D−, SBU1 and SBU2 are unconnected. The shell is tied to board GND.

VBUS passes C1 (1 µF, receptacle side), then F1 (100 mA PTC), then D1 (series diode, anode on the fuse side) to form VCC. C2 (4.7 µF) is the bulk capacitor on VCC; C3 (100 nF) sits at the MCU supply pins. D1 blocks current from VCC back into VBUS, for example from a programmer that drives its VCC pin. The fitted 1N4148W drops up to about 0.8 V at 20 mA; Section 12 recommends a Schottky instead.

### 3.2 MCU

U1 is an ATtiny84A running from VCC with no regulator, on its internal 8 MHz RC oscillator. XTAL1 and XTAL2 (PB0, PB1) and PA0 to PA3 are unused. RESET has a 10 kΩ pull-up (R3) to VCC.

### 3.3 LED drive

Each channel runs from VCC through a 680 Ω resistor to the LED anode; the cathode goes straight to an MCU pin. The LEDs are active-low: driving the pin low turns the LED on. The four pins are the ATtiny84A’s four hardware PWM outputs, split across Timer 0 (OC0A, OC0B) and Timer 1 (OC1A, OC1B).

With VBUS from 4.75 to 5.25 V, 0.5 to 0.8 V across D1, 1.8 to 2.4 V across the LED and 1% resistors, the current per LED is

ILED =

VBUS − VD1 − VF
R
∈ [2.26, 4.38] mA, | (1)

inside the 2 to 5 mA requirement. The voltage limits are provisional; repeat the calculation with the fitted LED’s datasheet values. A Schottky at D1 raises VCC by roughly 0.3 to 0.5 V and raises LED current slightly, so recheck the upper limit after that change.

### 3.4 Programming

J2 is a shrouded 2×3 AVR ISP header. SCK has its own pin (PA4). MOSI and MISO share pins with the SE and SW LED channels (PA6, PA5). The LED and its 680 Ω resistor load those lines while programming, so the SE and SW LEDs will flicker. A programmer with series resistance on MOSI may not pull the line far enough below the input-low threshold; a 1 kΩ LED resistor gives more margin. This has not been tested.

### 3.5 Test points

TP1 VBUS, TP2 VCC, TP3 GND and TP4 RESET are 1.5 mm round pads with their net names on the silkscreen.

### 4 Pin assignments

Pin | Port / function | Net | Use
1 | VCC | VCC | Supply
2 | PB0 / XTAL1 | none | Unused (internal clock)
3 | PB1 / XTAL2 | none | Unused (internal clock)
4 | PB3 / RESET | RESET | Reset, 10 kΩ pull-up, ISP
5 | PB2 / OC0A | LED_NW | NW LED, PWM
6 | PA7 / OC0B | LED_NE | NE LED, PWM
7 | PA6 / MOSI / OC1A | ISP_MO_SE | SE LED, PWM; ISP MOSI
8 | PA5 / MISO / OC1B | ISP_MI_SW | SW LED, PWM; ISP MISO
9 | PA4 / SCK | ISP_SCK | ISP clock only
10 to 13 | PA3, PA2, PA1, PA0/AREF | none | Unused
14 | GND | GND | Ground

Table 2: U1, ATtiny84A.

Pin | Signal | Net
1 | MISO | ISP_MI_SW
2 | VCC (sense) | VCC
3 | SCK | ISP_SCK
4 | MOSI | ISP_MO_SE
5 | RESET | RESET
6 | GND | GND
(a) J2, AVR ISP.
Pins | Net
A4, A9, B4, B9 | VBUS
A5 | USB_CC1 (R1 to GND)
B5 | USB_CC2 (R2 to GND)
A1, A12, B1, B12, shell | GND
A6 to A8, B6 to B8 | not connected
(b) J1, USB-C.

Table 3: Connector pinouts.

Position | LED | Resistor | U1 pin | PWM | Shared ISP signal | Centre (mm)
NW | D2 | R4 | 5 | OC0A | none | (8.5, 8.5)
NE | D3 | R5 | 6 | OC0B | none | (48.5, 8.5)
SE | D4 | R6 | 7 | OC1A | MOSI | (48.5, 48.5)
SW | D5 | R7 | 8 | OC1B | MISO | (8.5, 48.5)

Table 4: LED channels. Centres are measured from the board’s top-left corner, component side, y downwards.

### 5 Bill of materials

Every MPN is unverified. LCSC codes were matched from a third-party catalogue mirror on 22 September 2026 and have not been checked against a distributor. The same BOM is in fab/2026-09-21-UNVERIFIED/ as a JLCPCB CSV.

Ref | Qty | Value | Footprint | MPN | LCSC | What to verify
J1 | 1 | USB-C | GCT USB4105, 16P | USB4105-GF-A | C3020560 | Pinout, shell, edge-flush geom- etry, rating
F1 | 1 | 100 mA PTC | 0603 | MF-FSMF010X-2 | C210355 | Hold and trip current, voltage, resistance, derating
D1 | 1 | 1N4148W | SOD-123 | 1N4148W-7-F | C81598 | Replace with 1 A Schottky, then check reverse leakage (≤10 µA at 5 V) and forward drop
C1 | 1 | 1 µF X7R | 0603 | CC0603KRX7R9BB105 | none | Capacitance after DC bias, rat- ing
C2 | 1 | 4.7 µF | X7R,
| | ≥10 V | 0805 | GRM21BR71A475KA73L | none | More than 1 µF retained at 5 V bias
C3 | 1 | 100 nF X7R | 0603 | CC0603KRX7R9BB104 | C14663 | Rating, placement at U1
R1, R2 | 2 | 5.1 kΩ 1% | 0603 | RC0603FR-075K1L | C105580 | Value, tolerance
R3 | 1 | 10 kΩ 1% | 0603 | RC0603FR-0710KL | C98220 | Value, tolerance
R4 to R7 | 4 | 680 Ω 1% | 0603 | RC0603FR-07680RL | C112310 | Recalculate LED current from verified limits
D2 to D5 | 4 | Amber LED | 1206 | 150120AS75000 | C5478408 | Wavelength 590 to 605 nm, for- ward voltage at 2 to 5 mA, po- larity
U1 | 1 | ATtiny84A | SOIC-14, 3.9 mm | ATTINY84A-SSUR | C220597 | Supply current, lifecycle; tube part -SSU is C144333
J2 | 1 | AVR ISP 2×3 | IDC | 2.54 mm,
| | | vertical, THT | 61200621621 | none | Keying, pin 1, height
TP1 | to
TP4 | 4 | Test point | 1.5 mm pad | none | n/a | Bare copper; nothing to buy

Table 5: Bill of materials. 27 footprints in total: the 23 parts listed plus 4 mounting holes.

### 6 Power budget

Load | Worst case | Basis
CC terminations, R1 + R2 | 2.06 mA | 5.25 V across 5.1 kΩ −1%, twice
ATtiny84A | 10.00 mA | Reserved, pending datasheet confirmation
Passive leakage and margin | 1.00 mA | Allowance
Four LEDs | 17.52 mA | 4 × 4.38 mA
Total | 30.58 mA | Design ceiling 40 mA; hard limit <100 mA

Table 6: Steady-state supply current. With RESET held low, R3 draws up to about 0.5 mA more.

### 7 Firmware

AVR-GCC and avr-libc for an ATtiny84A at F_CPU = 8000000UL. Source in firmware/. Never compiled.

Timers | Timer 0: fast PWM, OC0A and OC0B non-inverting, clk/64. Timer 1: 8-bit fast PWM, OC1A and OC1B
| non-inverting, clk/64
PWM frequency | 8 MHz/64/256 ≈ 488 Hz on all four channels
Resolution | 8 bits; compare value is 255 − brightness because the LEDs are active-low
Fade | Triangle wave from an 8-bit phase counter, advanced every 4 ms: ≈1.02 s per cycle plus loop overhead
Offsets | NW 0, NE +64, SE +128, SW +192 (90◦ apart)
Build | make -C firmware gives quiet-orbit-qo-r1.hex; flags -Wall -Wextra -Werror
Checks | Compile-time error if F_CPU is not 8 MHz; all pin definitions are in pins.h only
Fuses | Default internal 8 MHz RC; clear CKDIV8 if the part ships with it set

Table 7: Firmware summary. Files: main.c (fade loop), led_pwm.c/.h (timers, brightness), pins.h (pin map from docs/PINOUT.md), Makefile.

### 8 PCB

### 8.1 Geometry

- 57×57 mm, 2 layers, 1.6 mm; all populated parts on the top side.
- LED optical centres on a 40 mm square centred on the board (Table 4). Each LED is vertical, cathode towards the horizontal centre line, resistor beside the anode.
- Four M3 holes, 3.2 mm NPTH, at (4, 4), (53, 4), (53, 53) and (4, 53) mm.
- USB-C centred on one edge and flush with it. C1, F1, D1 and C2 sit in a line directly behind it; C1 is 2.7 mm from the nearest VBUS pad.
- C3 is 2.4 mm from the MCU supply pin; R3 is 3.4 mm from RESET.

### 8.2 As committed

Footprints | 27
Track segments | 89
Track length | 376.5 mm: 320.8 mm top, 55.8 mm bottom
Track widths | 0.25, 0.3 and 0.5 mm
Vias | 24, 0.65 mm pad, 0.3 mm drill; 21 GND stitching, one each on VCC, ISP_SCK and RESET
Copper pours | GND on both layers
Keepouts | A no-track area across the pad gap of every two-pad part (17)
Fiducials | None

Table 8: Board statistics, measured from the committed .kicad_pcb.

### 8.3 Design rules

Our own conservative rules, not a particular fab’s.

Copper clearance | 0.2 mm
Track width | 0.25 mm signal, 0.5 mm power; minimum 0.2 mm
Via | 0.65 mm diameter, 0.3 mm drill
Copper to edge | 0.4 mm
Hole clearance | 0.25 mm board-wide. One scoped exception: 0.19 mm between J1 and itself, because the stock USB4105
land pattern puts its GND pads 0.194 mm from its own locating-peg holes
Silkscreen text | At least 1.0 mm high
Severities | KiCad defaults, no exclusions

Table 9: Design rules.

### 8.4 Board size

With the LEDs on a 40 mm square and holes 4 mm from each edge, the LED courtyard meets the mounting-hole courtyard on the corner diagonal, which sets the minimum size.

Board edge | LED to hole courtyard gap | Note
56.0 mm | −0.22 mm | Overlaps; 6 courtyard errors
56.5 mm | +0.13 mm | Smallest that passes
57.0 mm | +0.47 mm | This board
58.0 mm | +1.17 mm

Table 10: Courtyard clearance against board size.

57 mm is 32.5 cm²
, 34% less than a 70 mm board. Going smaller means moving the holes inside the LED square (about 46 mm) or also dropping the 40 mm LED pitch (about 31 mm); neither was laid out. Below 70 mm a single board may not qualify for a fab’s factory-programming assembly tier without panelising; the ISP header is the fallback.

### 8.5 Layout notes

- The J2 ground pin and SMD ground pads connect solidly to the pours, without thermal relief; the ISP tracks leave no room for spokes. J2’s ground pin will be harder to hand-solder.
- J1 is surface-mount only on the board edge, with no mechanical stakes beyond its shell tabs.
- Tracks run under the “USB-C 5V ONLY” text. The text is on mask and stays legible.
- The longest nets are ISP MOSI at about 55 mm and VCC at about 117 mm.
- Routing came from an autorouter. Placement is fixed; rerouting gives a slightly different track count each time.

### 9 Milky Way variant

Same circuit and placement, with artwork on the back: the Milky Way over a mountain, made from copper with a mask opening (gold on ENIG), copper under mask (purple), bare laminate (dark purple) and silkscreen for the
stars. Files are in hardware/variant-milkyway/; its .kicad_pcb and .kicad_pro replace the plain
board’s.
- 4 mm rounded corners.
- No back GND pour. The artwork’s gold frame, including eyelets round the M3 holes, is the back GND ring instead.
- The artwork copper is unconnected polygons cut back from every pad, via, track and hole. A fab reviewer may query the floating exposed copper; mention it on the order.
- Needs ENIG. HASL would tin the exposed copper.
- DRC after the artwork was added, all severities with schematic parity: 0 violations, 0 unconnected, 0 parity issues.

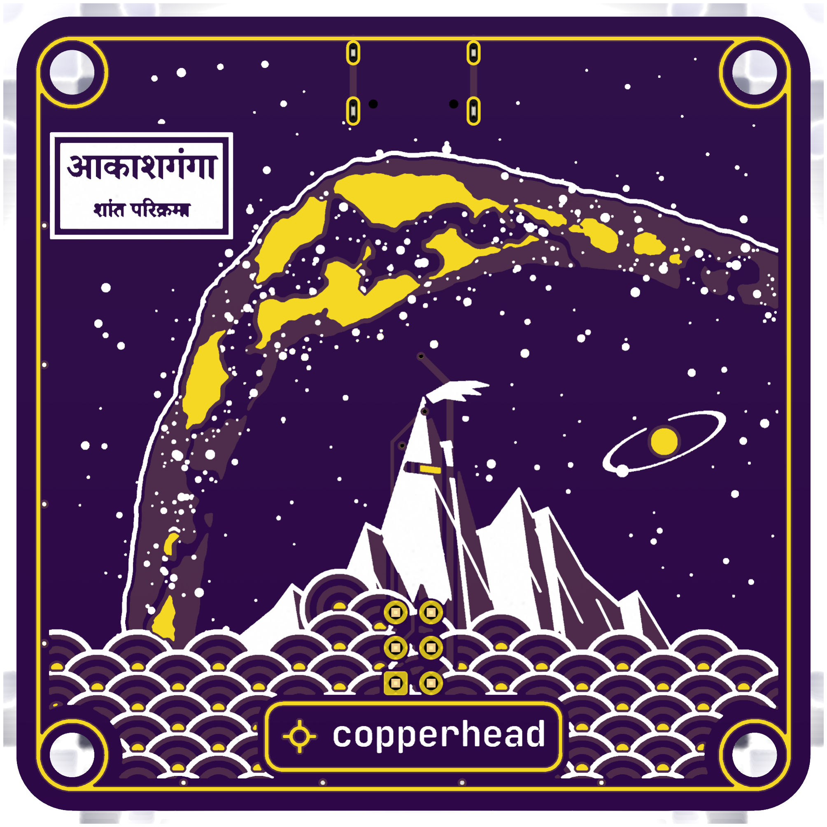
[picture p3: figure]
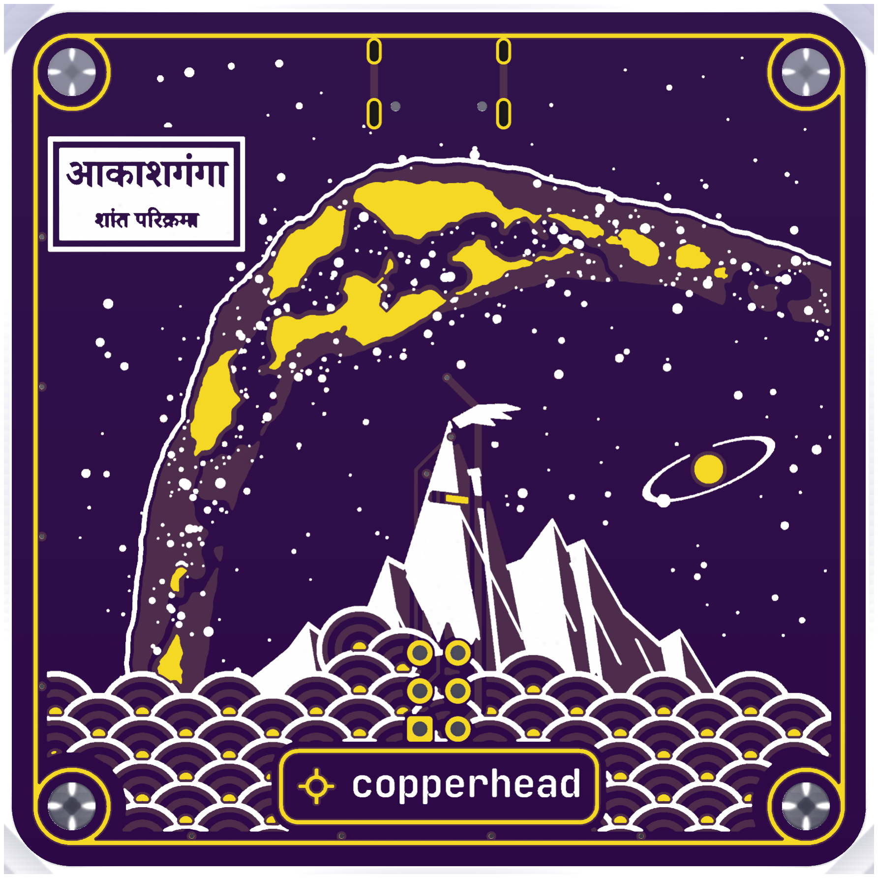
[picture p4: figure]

(a) Assembled. | (b) Bare board.

Figure 1: Milky Way back. KiCad renders.

### 10 Fabrication outputs

In fab/2026-09-21-UNVERIFIED/. Published so the design can be inspected; not a released fabrication package.

File | Contents
QO-R1-57mm-plain-jlcpcb.zip | Square board, GND pour on both sides
QO-R1-57mm-art-jlcpcb.zip | Milky Way back, 4 mm round corners, no back pour
plain/, art/ | The same gerbers unzipped, plus drill maps and .gbrjob
QO-R1-57mm-bom-jlcpcb.csv | BOM, transcribed, not verified; serves both boards
QO-R1-57mm-cpl-jlcpcb.csv | Placement, KiCad rotations, not corrected; serves both boards
plain-drc.json, art-drc.json | DRC reports taken just before plotting
make_bom_cpl.py | Generates the BOM and CPL

Table 11: Fabrication files.

Each zip | 11 files: copper, mask, paste and silkscreen for both sides, Edge_Cuts, PTH and NPTH drill. Drill maps and job file left out so a fab cannot mistake a map for a layer
Gerbers | kicad-cli 10.0.4; Protel extensions, no X2, no netlist attributes, mask subtracted from silk, zones refilled, 4.6 format
Drill | Excellon, mm, decimal, absolute origin, PTH and NPTH separate, oval holes in alternate mode
Drill sizes | PTH 0.30 (vias), 0.60, 1.00 mm; NPTH 0.65 (connector pegs), 3.20 mm (M3)
Outline | Reads as 57.1 mm because the outline line has width; the board is 57×57 mm
Order notes | Plain: any colour, HASL or ENIG. Art: purple mask, ENIG. Neither has an order-number placeholder

Table 12: Plot settings.

### 11 Verification status

Check | Result
ERC (KiCad 10.0.4, all severities) | 0 violations
DRC, plain board (all severities, schematic parity) | 0 violations, 0 unconnected, 0 parity
DRC, Milky Way board | 0 violations, 0 unconnected, 0 parity

Table 13: Checks run.

Not done: any physical build, power-on or measurement; compiling the firmware; checking any part against a current datasheet or distributor; a fab DFM check (the rules were compared with one fab’s published 2-layer limits from memory only); opening the gerbers in a viewer; programming through the ISP header with the LEDs fitted.

### 12 Open items

Item | Action
D1 is a 1N4148W signal diode in the power path; it drops up to about 0.8 V. | Fit a 1 A Schottky (B5819W or 1N5819HW class) in the same SOD-123 footprint. No layout change. Recheck LED current.
BOM unverified; C1, C2 and J2 have no LCSC match. | Verify every line against a datasheet and a distributor.
Test points: DNP in docs/BOM.md, in-BOM in the schematic. | Decide which is right and make the other match.
ISP MOSI shares a pin with the SE LED through 680 Ω. | Test with the intended programmer; consider 1 kΩ for R6 and R7.
J1 GND pads 0.194 mm from its NPTH pegs. | Expect a query from fabs with a 0.2 mm limit.
CPL rotations uncorrected. | Check U1, J1 and the five diodes in the assembler’s placement preview.
0.47 mm between LED and M3 hole courtyards. | Allow for the screw head in enclosure baffles; 58 to 60 mm gives more room.

Table 14: Open items before ordering.

### 13 Licence

Hardware (hardware/, fab/, 3d/) is CERN-OHL-S-2.0. Firmware (firmware/) is GPL-3.0-only. Documen-tation and images (docs/, images/, README files) are CC-BY-4.0. Footprints and symbols in hardware/libs/ and hardware/sym-lib-cache/ come from the KiCad libraries (CC-BY-SA 4.0 with the design-use exception). The copperhead mark on the silkscreen is a trademark and is not covered by these licences; remove it from modified boards. No warranty: this design has not been built or tested.

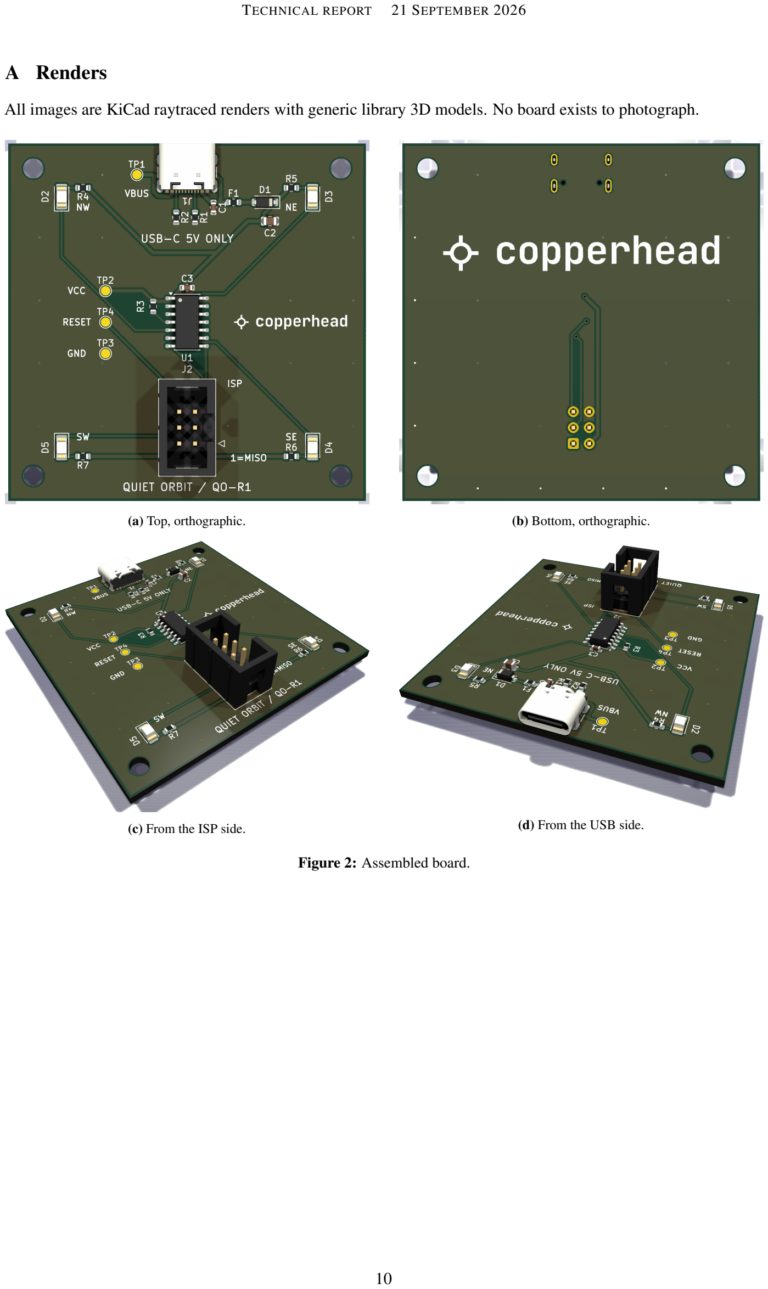
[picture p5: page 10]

A Renders

All images are KiCad raytraced renders with generic library 3D models. No board exists to photograph.

(a) Top, orthographic. | (b) Bottom, orthographic.
(c) From the ISP side. | (d) From the USB side.

Figure 2: Assembled board.

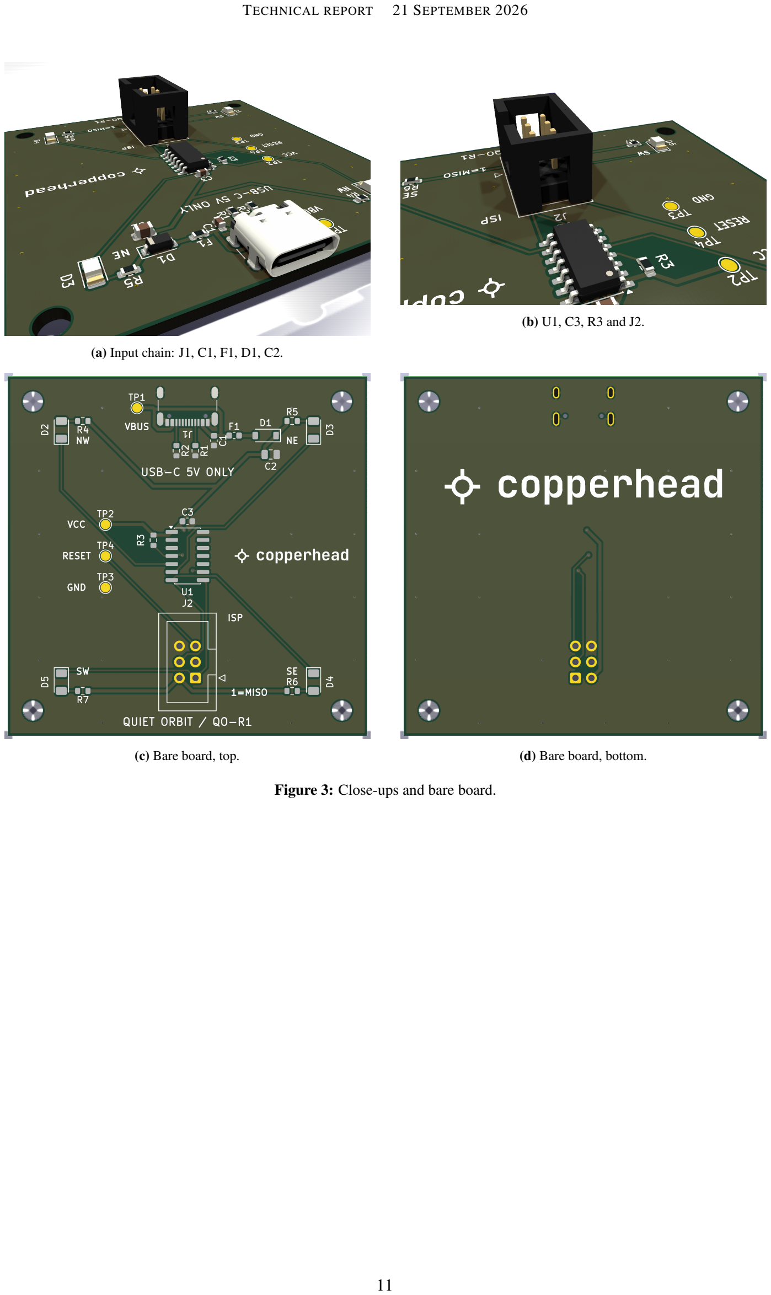
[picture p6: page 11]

(a) Input chain: J1, C1, F1, D1, C2.
(b) U1, C3, R3 and J2.
(c) Bare board, top. | (d) Bare board, bottom.

Figure 3: Close-ups and bare board.

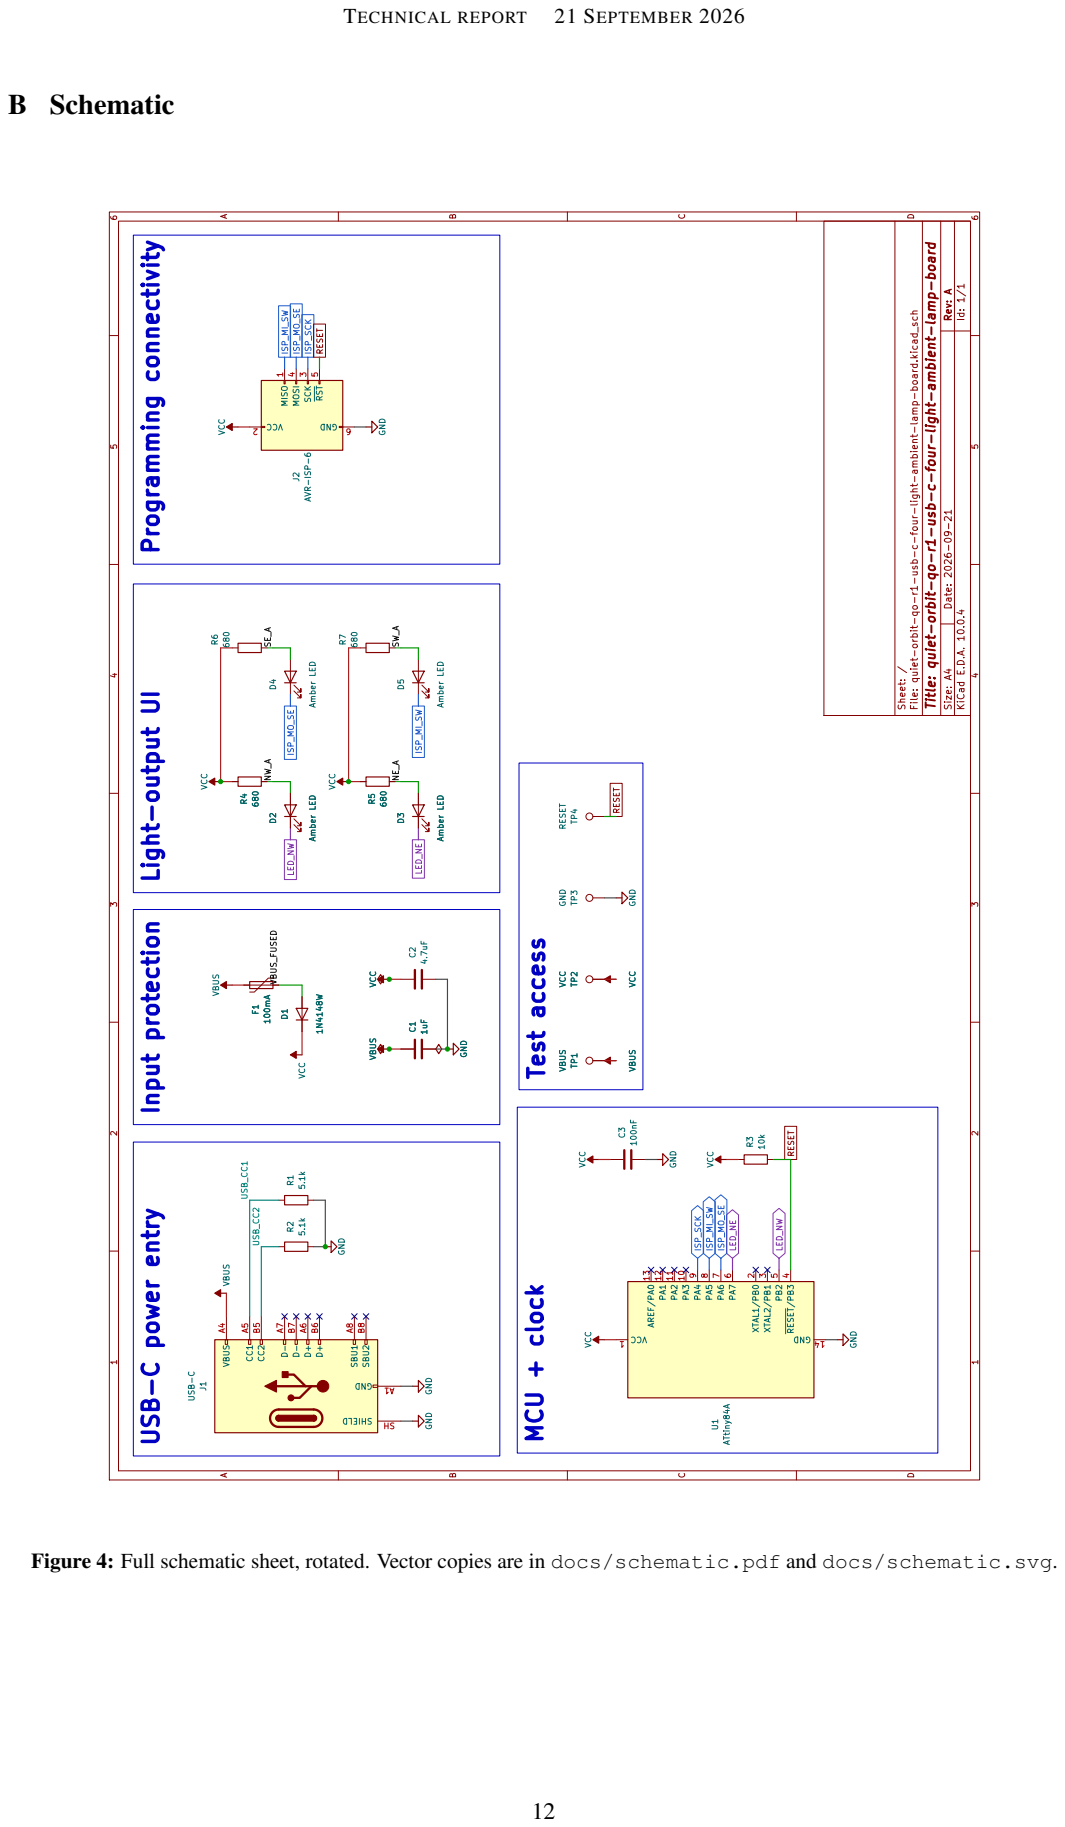
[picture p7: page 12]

VBUS_FUSED Programming connectivity USB-C power entry

Title: quiet-orbit-qo-r1-usb-c-four-light-ambient-lamp-board

File: quiet-orbit-qo-r1-usb-c-four-light-ambient-lamp-board.kicad_sch

SCK 3 MOSI 4 RST 5 GND

Figure 4: Full schematic sheet, rotated. Vector copies are in docs/schematic.pdf and docs/schematic.svg.

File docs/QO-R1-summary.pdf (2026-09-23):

TECHNICAL REPORT 21 SEPTEMBER 2026

# Quiet Orbit QO-R1: Summary

## copperhead

https://github.com/copperheadhq/copperhead-quiet-orbit

A USB-C powered four-LED ambient lamp board, 57×57 mm

Abstract

QO-R1 is a two-layer, 57×57 mm board that drives four amber LEDs from an ATtiny84A, each on its own hardware PWM channel, powered from USB-C at 5 V. This note lists the hard facts: key figures, channel map, bill of materials, board statistics and the checks required before ordering. The board has not been fabricated, the firmware has not been compiled, and every part number is unverified. The full description is in the companion report, QO-R1-reference.pdf.

Status: not built, not tested.
- No board has been fabricated or powered.
- The firmware has not been compiled.
- Every part number in the BOM is unverified.
- D1 (1N4148W) is the wrong part. Fit a 1 A Schottky (B5819W or 1N5819HW class) in the same SOD-123 footprint.

## 1 Key figures

Parameter | Value
Board | 57×57 mm, 2 layers, 1.6 mm, all parts on top
Input | USB-C, 5 V sink only; 5.1 kΩ on CC1 and CC2; no data, no PD
Protection | 100 mA PTC (F1), series diode (D1)
MCU | ATtiny84A, SOIC-14, internal 8 MHz RC oscillator
LEDs | 4 × amber, 1206, 590 to 605 nm, active-low
LED current | 2.26 to 4.38 mA each (calculated, 680 Ω)
PWM | 4 hardware channels, 8-bit, ≈488 Hz
Fade | Triangle, ≈1.0 s period, channels 90◦ apart
Supply current | 30.6 mA calculated maximum; requirement <100 mA
LED positions | Corners of a 40 mm square centred on the board
Mounting | 4 × M3, 3.2 mm NPTH, centres 4 mm from each edge
Programming | 2×3 AVR ISP, 2.54 mm; powered from USB, ISP VCC is sense only
Enclosure | 80×80×25 mm, four light windows

Table 1: Key figures.

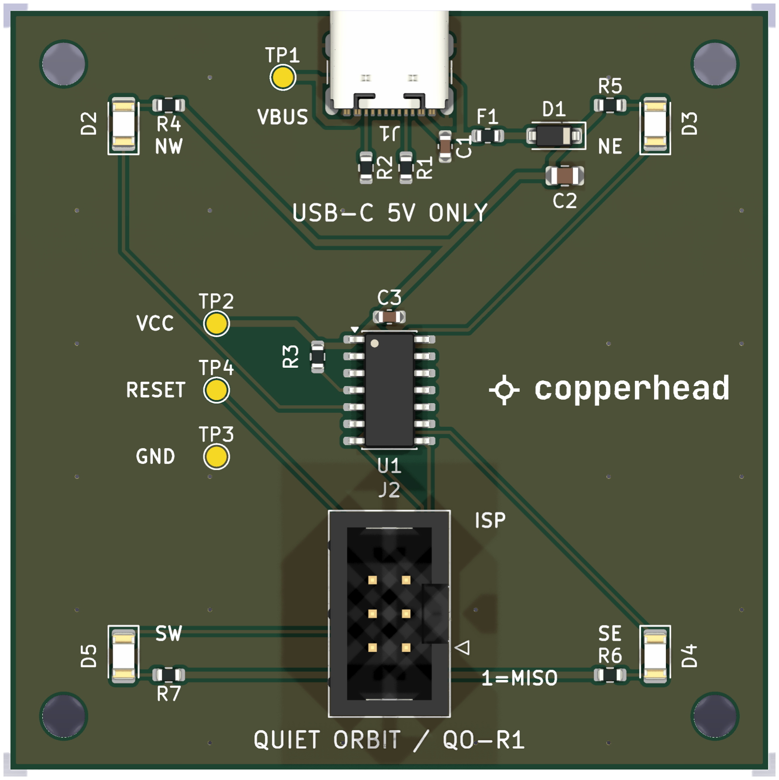
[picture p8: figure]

Figure 1: Top side. KiCad render, not a photograph.

## 2 LED channels

Position | LED | Resistor | U1 pin | PWM output | Shared with
NW | D2 | R4 | 5 (PB2) | OC0A | none
NE | D3 | R5 | 6 (PA7) | OC0B | none
SE | D4 | R6 | 7 (PA6) | OC1A | ISP MOSI
SW | D5 | R7 | 8 (PA5) | OC1B | ISP MISO

Table 2: LED channel map. SCK (pin 9) and RESET (pin 4) carry no LED; RESET has a 10 kΩ pull-up.

3 Schematic 1 | 2 | 3 | 4 | 5 | 6

# VBUS GND

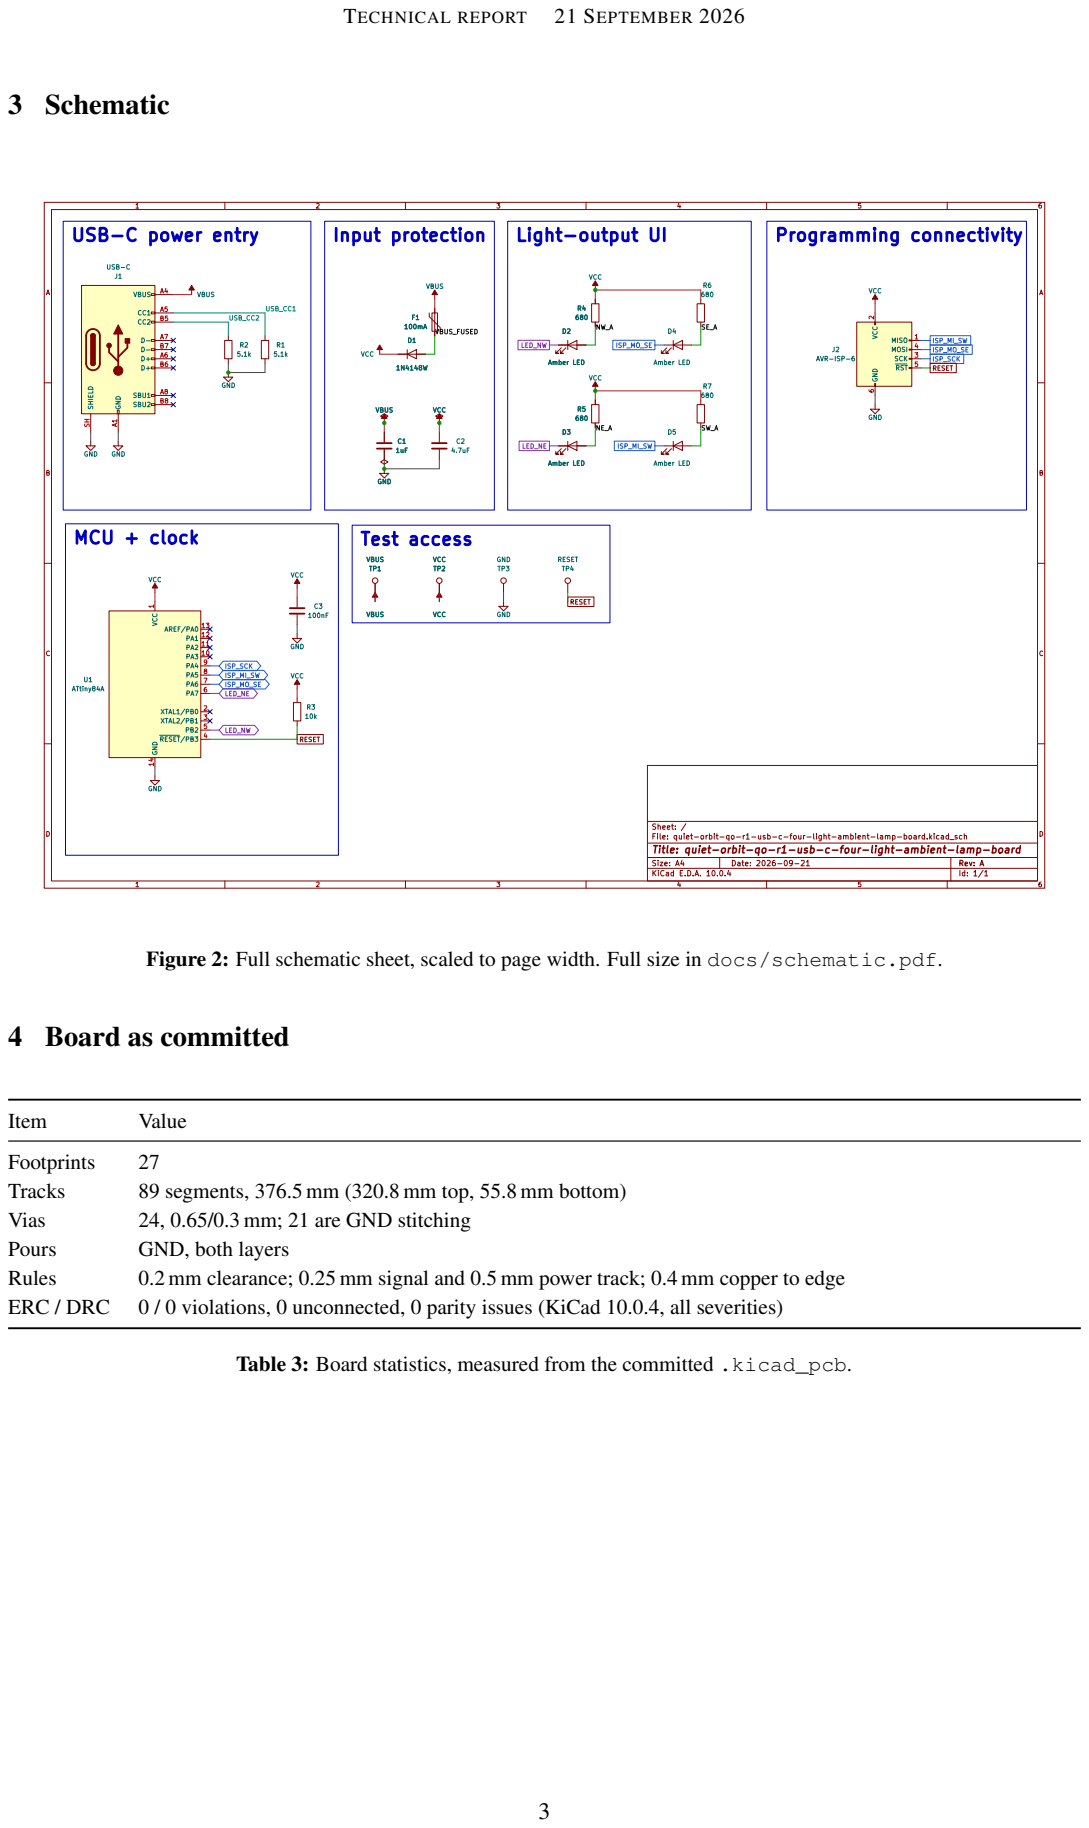
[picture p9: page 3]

SCK 3 MOSI 4 RST 5 GND

Sheet: /
File: quiet-orbit-qo-r1-usb-c-four-light-ambient-lamp-board.kicad_sch
Title: quiet-orbit-qo-r1-usb-c-four-light-ambient-lamp-board
KiCad E.D.A. 10.0.4

Figure 2: Full schematic sheet, scaled to page width. Full size in docs/schematic.pdf.

Table 3: Board statistics, measured from the committed .kicad_pcb.

## 5 Bill of materials

Ref | Value | Package | MPN (unverified) | LCSC
J1 | USB-C receptacle | GCT USB4105, 16P | USB4105-GF-A | C3020560
F1 | PTC, 100 mA hold | 0603 | MF-FSMF010X-2 | C210355
D1 | 1N4148W (replace with 1 A Schottky) | SOD-123 | 1N4148W-7-F | C81598
C1 | 1 µF X7R | 0603 | CC0603KRX7R9BB105 | none found
C2 | 4.7 µF X7R | 0805 | GRM21BR71A475KA73L | none found
C3 | 100 nF X7R | 0603 | CC0603KRX7R9BB104 | C14663
R1, R2 | 5.1 kΩ 1% | 0603 | RC0603FR-075K1L | C105580
R3 | 10 kΩ 1% | 0603 | RC0603FR-0710KL | C98220
R4 to R7 | 680 Ω 1% | 0603 | RC0603FR-07680RL | C112310
D2 to D5 | Amber LED | 1206 | 150120AS75000 | C5478408
U1 | ATtiny84A | SOIC-14 | ATTINY84A-SSUR | C220597
J2 | AVR ISP 2×3, shrouded | 2.54 mm THT | 61200621621 | none found
TP1 to TP4 | VBUS, VCC, GND, RESET | 1.5 mm pad | bare pad | n/a

Table 4: Bill of materials. LCSC codes were matched from a third-party catalogue mirror on 22 September 2026.

## 6 Checks before ordering

- Replace D1 with a Schottky, as above. The layout does not change.
- Verify every BOM line against a datasheet and a distributor. Three lines have no LCSC match.
- Open the gerbers in a viewer. Nobody has done this yet, and no fab has run a DFM check.
- The J1 footprint puts GND pads 0.194 mm from its NPTH locating pegs. A fab with a 0.2 mm limit will query it.
- CPL rotations are KiCad’s and have not been corrected for any assembler.
- Test points are DNP in docs/BOM.md but in the BOM in the schematic. One of the two is wrong.
- The LED and M3 hole courtyards are 0.47 mm apart at each corner. An enclosure baffle must fit round the screw head.

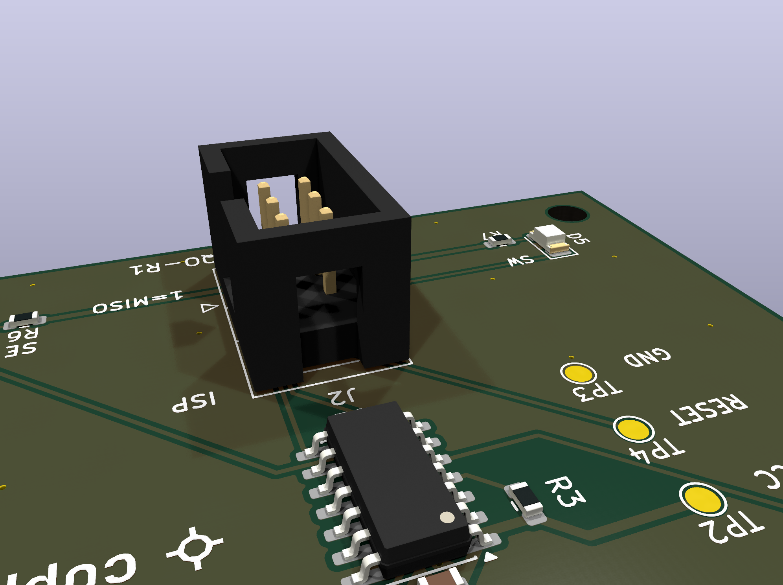
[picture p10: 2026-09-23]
images/09-closeup-mcu-isp.png

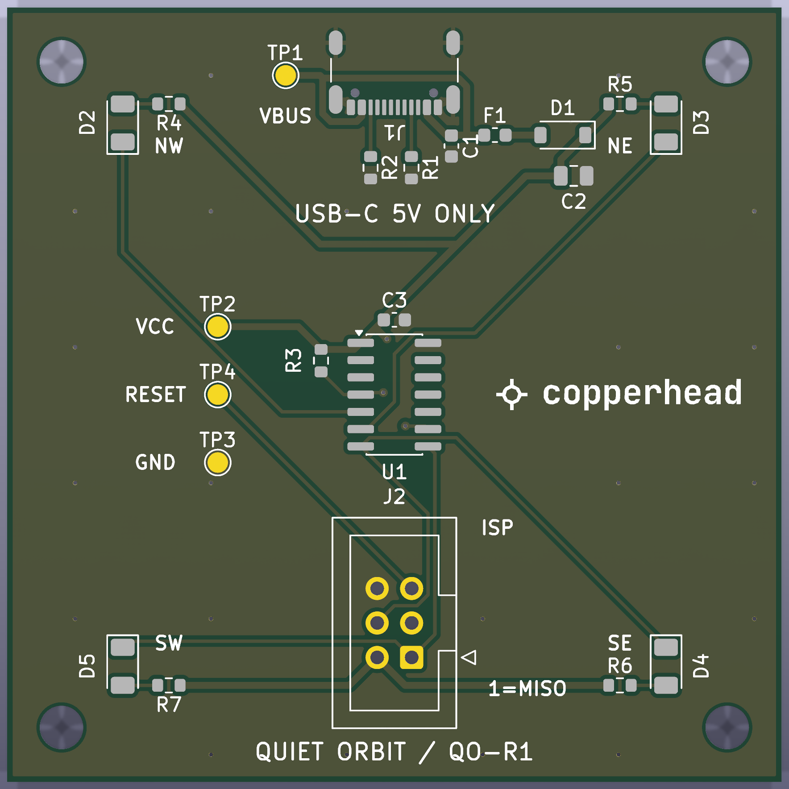
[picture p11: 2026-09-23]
images/bare-top.png

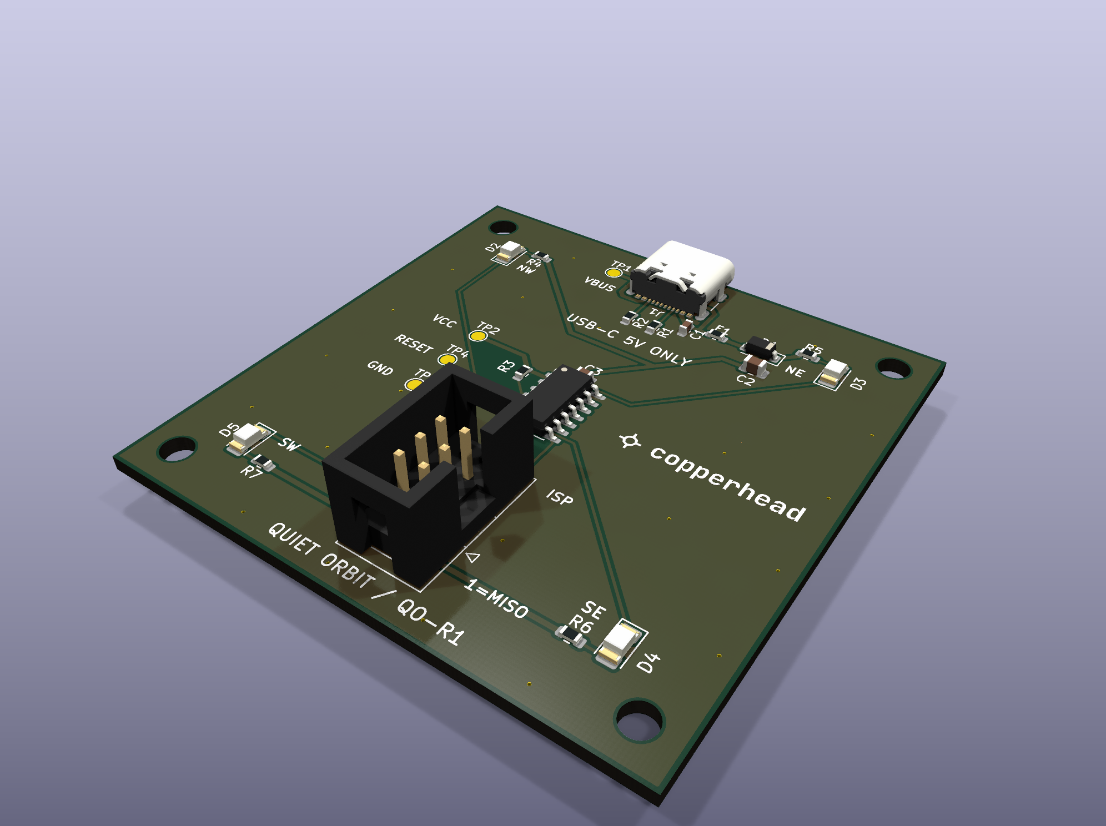
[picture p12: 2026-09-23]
images/04-iso-front-right.png

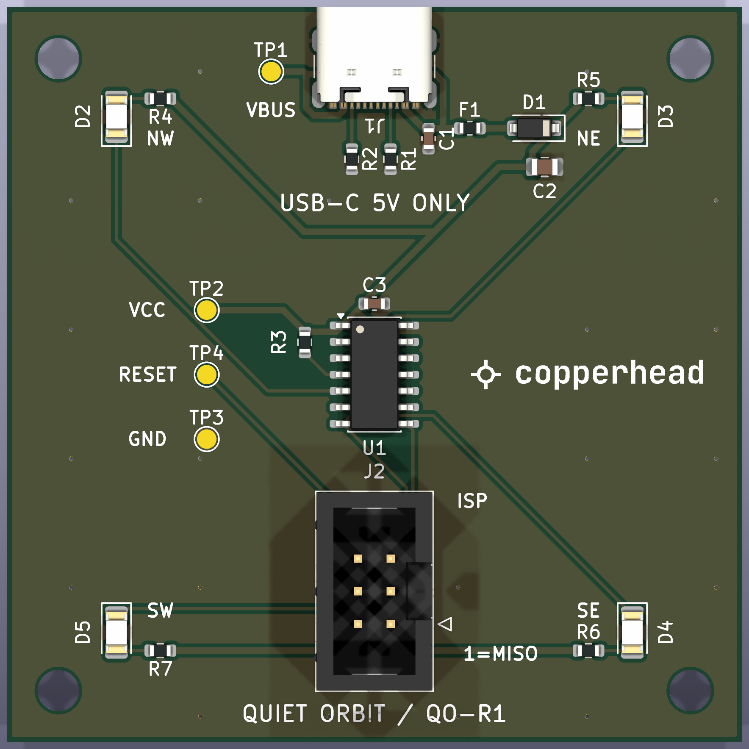
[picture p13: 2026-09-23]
images/01-top.png

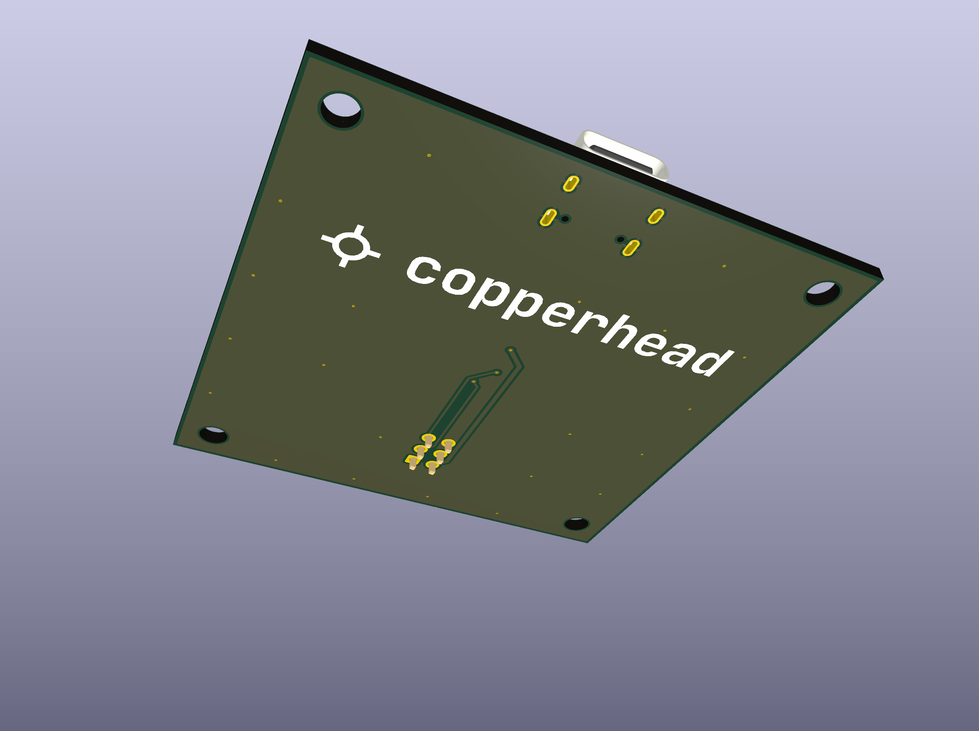
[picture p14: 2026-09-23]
images/07-back-iso.png

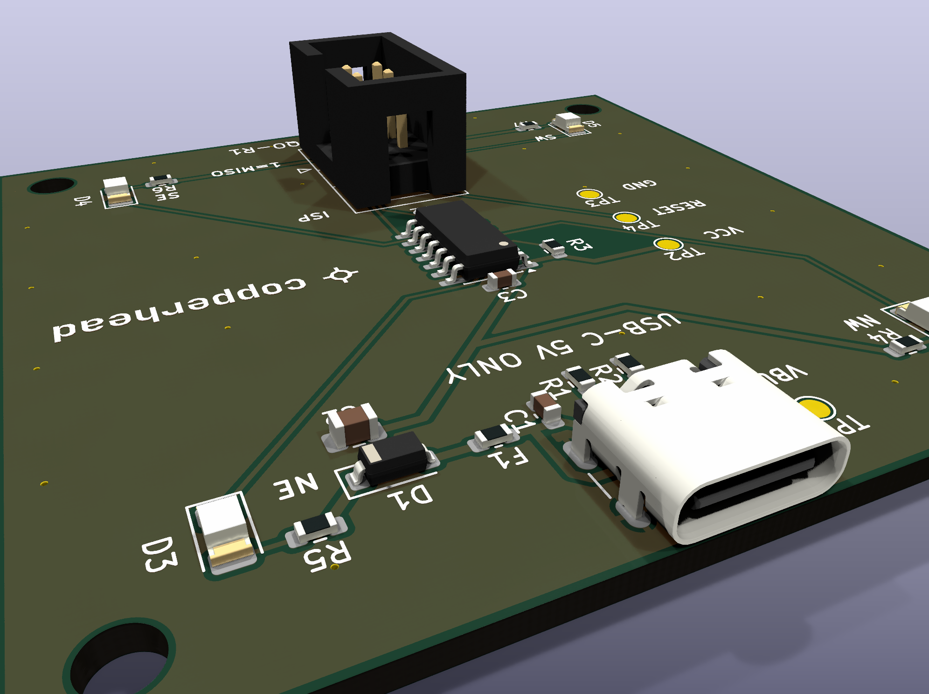
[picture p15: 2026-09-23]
images/08-closeup-usb-input.png

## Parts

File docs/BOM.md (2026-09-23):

# Quiet Orbit QO-R1 Bill of Materials

Every purchasable MPN below is **UNVERIFIED** pending review of the current manufacturer datasheet, distributor stock, lifecycle status, and footprint drawing before release. Each rationale states the properties to verify. Value entries contain schematic component values only.

| Refdes | Value | Footprint | MPN | Rationale |
|---|---|---|---|---|
| J1 | USB-C | Connector_USB:USB_C_Receptacle_GCT_USB4105-xx-A_16P_TopMnt_Horizontal | USB4105-GF-A (UNVERIFIED) | Power-only 16-pin receptacle; verify VBUS, GND, CC, shell, edge-flush geometry, rating, and footprint. Installed `Connector:USB_C_Receptacle_USB2.0_16P` is one unit with confirmed A/B package pins and SH. |
| F1 | 100mA | Fuse:Fuse_0603_1608Metric | MF-FSMF010X-2 (UNVERIFIED) | Verify 100 mA hold, at least 200 mA trip at 25 °C, voltage, resistance, tolerance, derating, and footprint. No quiescent current beyond series loss. Installed `Device:Polyfuse` has pins 1 and 2. |
| D1 | 1N4148W | Diode_SMD:D_SOD-123 | 1N4148W-7-F (UNVERIFIED) | Silicon reverse blocker; verify no more than 10 µA reverse leakage at room temperature and 5 V, no more than 0.8 V forward drop near 20 mA, rating, polarity, and package. Installed diode mapping uses pin 1 K and pin 2 A. |
| C1 | 1uF | Capacitor_SMD:C_0603_1608Metric | CC0603KRX7R9BB105 (UNVERIFIED) | Verify capacitance, X7R dielectric, rating, tolerance, DC-bias loss, leakage, and footprint. The 1 µF receptacle-side value is below the 10 µF limit. |
| C2 | 4.7uF | Capacitor_SMD:C_0805_2012Metric | GRM21BR71A475KA73L (UNVERIFIED) | Verify X7R, at least 10 V rating, tolerance, leakage, footprint, and more than 1 µF retained capacitance at operating bias. |
| C3 | 100nF | Capacitor_SMD:C_0603_1608Metric | CC0603KRX7R9BB104 (UNVERIFIED) | MCU bypass; verify X7R, rating, tolerance, leakage, and footprint; place directly at U1 VCC/GND. |
| R1 | 5.1k | Resistor_SMD:R_0603_1608Metric | RC0603FR-075K1L (UNVERIFIED) | Independent CC1 Rd; verify value, 1% tolerance, rating, and footprint. Worst-case draw is about 1.03 mA at 5.25 V and -1% tolerance. |
| R2 | 5.1k | Resistor_SMD:R_0603_1608Metric | RC0603FR-075K1L (UNVERIFIED) | Independent CC2 Rd; verify value, 1% tolerance, rating, and footprint. Worst-case draw is about 1.03 mA. |
| R3 | 10k | Resistor_SMD:R_0603_1608Metric | RC0603FR-0710KL (UNVERIFIED) | RESET pull-up; verify value, 1% tolerance, rating, and footprint. Normal draw is negligible; RESET-low draw is at most about 0.525 mA. |
| U1 | ATtiny84A | Package_SO:SOIC-14_3.9x8.7mm_P1.27mm | ATTINY84A-SSUR (UNVERIFIED) | Verify 5 V operation, 8 MHz internal RC, supply-current maximum, PWM/ISP functions, lifecycle, and SOIC-14 drawing. Installed one-unit `MCU_Microchip_ATtiny:ATtiny84A-P` has the compatible 14-pin numbering: VCC 1, RESET/PB3 4, PA7..PA0 6..13, GND 14. Budget reserves 10 mA pending datasheet confirmation. |
| D2 | Amber LED | LED_SMD:LED_1206_3216Metric | 150120AS75000 (UNVERIFIED) | NW LED; verify 590–605 nm, forward-voltage bounds at 2–5 mA, optical consistency, polarity, and 1206 package. Installed `Device:LED` uses pin 1 K and pin 2 A. |
| D3 | Amber LED | LED_SMD:LED_1206_3216Metric | 150120AS75000 (UNVERIFIED) | NE LED; same datasheet checks as D2. |
| D4 | Amber LED | LED_SMD:LED_1206_3216Metric | 150120AS75000 (UNVERIFIED) | SE LED; same datasheet checks as D2. |
| D5 | Amber LED | LED_SMD:LED_1206_3216Metric | 150120AS75000 (UNVERIFIED) | SW LED; same datasheet checks as D2. |
| R4 | 680 | Resistor_SMD:R_0603_1608Metric | RC0603FR-07680RL (UNVERIFIED) | NW LED resistor; verify value, 1% tolerance, rating, and footprint. With 4.75–5.25 V VBUS, 0.5–0.8 V D1 drop, 1.8–2.4 V LED drop, and resistor tolerance, current is about 2.26–4.38 mA; repeat using verified limits. |
| R5 | 680 | Resistor_SMD:R_0603_1608Metric | RC0603FR-07680RL (UNVERIFIED) | NE LED resistor; same provisional 2.26–4.38 mA calculation and checks as R4. |
| R6 | 680 | Resistor_SMD:R_0603_1608Metric | RC0603FR-07680RL (UNVERIFIED) | SE LED resistor; same provisional 2.26–4.38 mA calculation and checks as R4. |
| R7 | 680 | Resistor_SMD:R_0603_1608Metric | RC0603FR-07680RL (UNVERIFIED) | SW LED resistor; same provisional 2.26–4.38 mA calculation and checks as R4. |
| J2 | AVR-ISP-6 | Connector_IDC:IDC-Header_2x03_P2.54mm_Vertical | 61200621621 (UNVERIFIED) | Verify 2 × 3 positions, 2.54 mm pitch, numbering, key, height, footprint, and pin-1 marking. Installed `Connector_Generic:Conn_02x03_Odd_Even` is one unit with pins 1–6. VCC is sense-only. |
| TP1 | VBUS | TestPoint:TestPoint_Pad_D1.5mm | DNP | Bare PCB pad; no purchased MPN. Installed `Connector:TestPoint` has pin 1. The 1.5 mm pad exceeds the 1.0 mm minimum; preserve 0.5 mm clearance. |
| TP2 | VCC | TestPoint:TestPoint_Pad_D1.5mm | DNP | Bare protected-VCC PCB pad; same symbol and mechanical checks as TP1. |
| TP3 | GND | TestPoint:TestPoint_Pad_D1.5mm | DNP | Bare GND PCB pad; same symbol and mechanical checks as TP1. |
| TP4 | RESET | TestPoint:TestPoint_Pad_D1.5mm | DNP | Bare RESET PCB pad; same symbol and mechanical checks as TP1. |

## Electrical budget closure

- CC termination worst case is approximately 2.06 mA total.
- U1 reserves 10 mA pending datasheet confirmation. Allowing another 1 mA for all passive leakage and margin gives a provisional 13.06 mA non-LED total, below 20 mA.
- Four LED channels at the provisional 4.38 mA maximum total 17.52 mA, below 20 mA.
- The provisional expected maximum is 30.58 mA, below the 40 mA ceiling and strict 100 mA USB limit. Final release requires replacing every UNVERIFIED check with current datasheet and distributor evidence.
- D1 is the intentional reverse-current element; its exact maximum leakage at 5 V and room temperature must be confirmed as no more than 10 µA.

## Symbol and capture notes

Installed-library searches and pin inspections were completed for U1, J1, J2, D1, D2–D5, F1, and TP1–TP4. All selected symbols are single-unit. Resistors and capacitors use standard `Device:R` and `Device:C`. J1 D+, D−, SBU1, and SBU2 are intentionally unconnected because the product is power-only.

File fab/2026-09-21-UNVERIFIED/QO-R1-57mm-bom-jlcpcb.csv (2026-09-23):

Comment | Designator | Footprint | LCSC Part # | MPN | Note
1uF | C1 | C_0603_1608Metric |  | CC0603KRX7R9BB105 | no LCSC match for this MPN
4.7uF | C2 | C_0805_2012Metric |  | GRM21BR71A475KA73L | no LCSC match for this MPN
100nF | C3 | C_0603_1608Metric | C14663 | CC0603KRX7R9BB104 | basic
1N4148W | D1 | D_SOD-123 | C81598 | 1N4148W-7-F | basic; listed as 1N4148W, not the -7-F MPN. Wrong part for the power path, fit a Schottky
Amber LED | D2,D3,D4,D5 | LED_1206_3216Metric | C5478408 | 150120AS75000 | extended; stock 100
100mA | F1 | Fuse_0603_1608Metric | C210355 | MF-FSMF010X-2 | extended
USB-C | J1 | USB_C_Receptacle_GCT_USB4105-xx-A_16P_TopMnt_Horizontal | C3020560 | USB4105-GF-A | extended
AVR-ISP-6 | J2 | IDC-Header_2x03_P2.54mm_Vertical |  | 61200621621 | through-hole; no LCSC match for this MPN
5.1k | R1,R2 | R_0603_1608Metric | C105580 | RC0603FR-075K1L | extended
10k | R3 | R_0603_1608Metric | C98220 | RC0603FR-0710KL | extended; stock 22
680 | R4,R5,R6,R7 | R_0603_1608Metric | C112310 | RC0603FR-07680RL | extended; stock 71
ATtiny84A | U1 | SOIC-14_3.9x8.7mm_P1.27mm | C220597 | ATTINY84A-SSUR | extended; stock 5 (the tube part, -SSU, is C144333, stock 40)

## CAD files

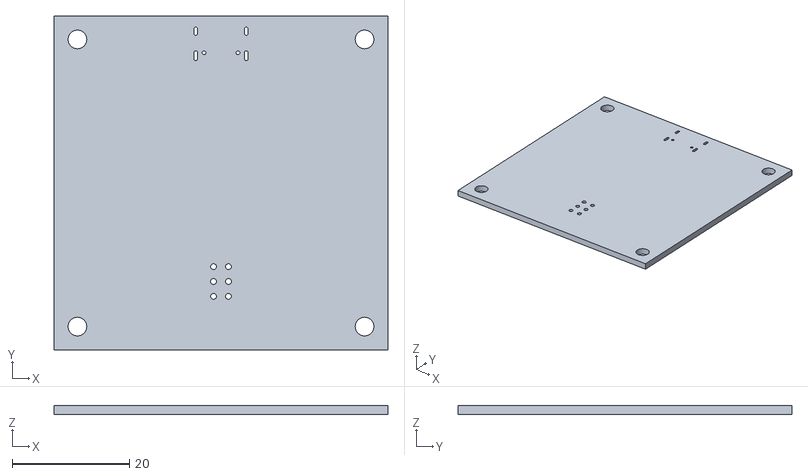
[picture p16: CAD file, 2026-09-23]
3d/quiet-orbit-57mm-board-only.stl
57.0 x 57.0 x 1.51

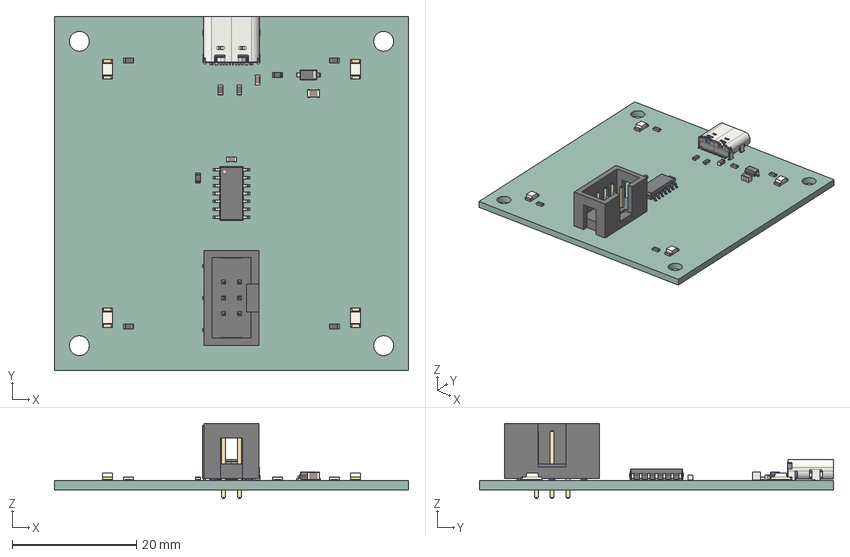
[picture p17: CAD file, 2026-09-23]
3d/quiet-orbit-57mm-mechanical.step
57.0 x 57.0 x 12.1 mm
D_SOD-123
C_0603_1608Metric x 2
R_0603_1608Metric x 7
USB_C_Receptacle_16P_TopMnt_Horizontal_GCT_USB4105-xx-A
LED_1206_3216Metric x 4
Fuse_0603_1608Metric
IDC_Header_2x03_P254mm_Vertical
SOIC-14_3.9x8.7mm_P1.27mm
C_0805_2012Metric
quiet-orbit-qo-r1-usb-c-four-light-ambient-lamp-board_PCB

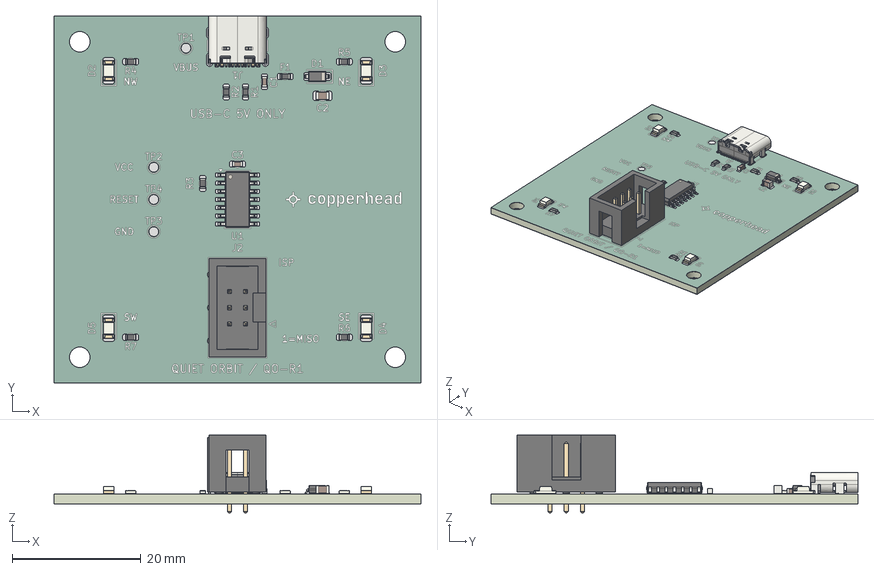
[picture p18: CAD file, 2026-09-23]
3d/quiet-orbit-57mm.step
57.0 x 57.0 x 12.1 mm
D_SOD-123
C_0603_1608Metric x 2
R_0603_1608Metric x 7
USB_C_Receptacle_16P_TopMnt_Horizontal_GCT_USB4105-xx-A
LED_1206_3216Metric x 4
Fuse_0603_1608Metric
IDC_Header_2x03_P254mm_Vertical
SOIC-14_3.9x8.7mm_P1.27mm
C_0805_2012Metric
quiet-orbit-qo-r1-usb-c-four-light-ambient-lamp-board_copper
quiet-orbit-qo-r1-usb-c-four-light-ambient-lamp-board_pad
quiet-orbit-qo-r1-usb-c-four-light-ambient-lamp-board_via
quiet-orbit-qo-r1-usb-c-four-light-ambient-lamp-board_silkscreen x 2
quiet-orbit-qo-r1-usb-c-four-light-ambient-lamp-board_soldermask x 2
quiet-orbit-qo-r1-usb-c-four-light-ambient-lamp-board_PCB

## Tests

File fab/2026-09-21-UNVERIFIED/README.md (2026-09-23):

# Fabrication outputs (UNVERIFIED)

**Plotted 2026-09-21 from a board that has never been fabricated, from a BOM in which every
part number is unverified, with one known-wrong part fitted (D1 is a
1N4148W signal diode in the power path; use a 1 A Schottky in the same footprint). These files are published so
the design can be inspected. They are not a released fabrication package.**

If you send these to a fab, that decision is yours.

## What is here

| File | Board |
|---|---|
| `QO-R1-57mm-plain-jlcpcb.zip` | square outline, GND pour both sides |
| `QO-R1-57mm-art-jlcpcb.zip` | Milky Way artwork on the back, 4 mm round corners, no back pour |
| `plain/`, `art/` | the same gerbers unzipped, plus drill maps and `.gbrjob` |
| `QO-R1-57mm-bom-jlcpcb.csv` | BOM, transcribed and not verified |
| `QO-R1-57mm-cpl-jlcpcb.csv` | component placement, rotations uncorrected |
| `plain-drc.json`, `art-drc.json` | the DRC reports taken immediately before plotting |
| `make_bom_cpl.py` | how the BOM and CPL were generated |

Each zip holds 11 files: front and back copper, mask, paste and silkscreen, `Edge_Cuts.gm1`,
`PTH.drl` and `NPTH.drl`. Drill maps and `.gbrjob` are left out of the zips deliberately so a
fab's parser cannot mistake a map for a layer. One BOM and CPL pair serves both boards: the
two schematics are byte-identical and the position exports are the same.

## How they were made

`kicad-cli` 10.0.4. Gerbers: Protel extensions, no X2, no netlist attributes, soldermask
subtracted from silk, zones refilled, 4.6 precision. Drill: Excellon, mm, decimal, absolute
origin, PTH and NPTH separate, oval holes in alternate mode. Drills used: PTH 0.30 (vias),
0.60, 1.00 mm; NPTH 0.65 (connector pegs), 3.20 mm (M3).

DRC ran immediately before plotting with `--severity-all --schematic-parity`: 0 violations,
0 unconnected, 0 parity on both boards. The reports are the `*-drc.json` files here.

## What has not been done

- No fab has DFM-checked these. The rules used are our own conservative set, not a
  named manufacturer's. They were compared against one fab's published 2-layer limits from
  memory only.
- Likely to be queried: the connector's GND pads are 0.194 mm from its own 0.65 mm NPTH
  locating pegs. This is the stock land pattern for that part, and it needs a scoped rule in
  the `.kicad_dru` to pass. Many fabs list 0.2 mm as their NPTH-to-copper floor.
- These have not been opened in a gerber viewer. Do that before you pay for anything.
- The BOM is a transcription. The schematic carries no MPN or supplier field; the part
  numbers come from `docs/BOM.md`, where their author marks every one UNVERIFIED, and the
  supplier codes came from a third-party catalogue mirror on 2026-09-22. None was checked
  against a distributor or a datasheet. Three parts had no match and are left blank. D1 is
  listed as the schematic has it; replace it with a Schottky before ordering.
- Rotations are KiCad's, uncorrected. Assembly houses use a different zero for some
  packages. The SOIC, the USB-C receptacle and the five diodes are the ones to check in a
  placement preview.
- The ISP header is through-hole and is in both files; most assembly services fit it by
  hand at extra cost, or you solder it yourself.
- Test points are omitted from the BOM: they are bare copper pads with nothing to buy.

## If you order the art board

Purple soldermask and ENIG. The artwork is exposed copper, and HASL would tin it. The M3
eyelets and frame are exposed GND, and the large areas of floating exposed copper are
intentional; say so in the order remark if an engineer queries it. Neither board carries an
order-number placeholder, so a fab will put its number wherever it likes unless you ask
otherwise. On the art board, that means somewhere in the picture.

Board size reads as 57.1 mm in the file because the outline line has width. The board is
57 × 57 mm, 2 layers, 1.6 mm.

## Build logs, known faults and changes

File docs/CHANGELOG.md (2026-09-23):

# Design changelog

## 2026-09-21: create pipeline stage: devplan

- Change: create-devplan-stage
- Files: docs/DEVPLAN.md, docs/CHANGELOG.md, docs/DECISIONS.md
- Verification: ERC clean, DRC clean

## 2026-09-21: create pipeline stage: devplan

- Change: create-devplan-stage
- Files: docs/DEVPLAN.md, docs/CHANGELOG.md, docs/DECISIONS.md
- Verification: ordered bring-up traces TP1 VBUS, TP2 VCC, TP3 GND, and TP4 RESET to measurable stop conditions; prototype ordering is gated on completed routing, verified parts and footprints, restored release DRC checks, regenerated outputs, and staged validation; ERC, DRC, legibility, and documentation drift must remain clean.

## 2026-09-21: create pipeline stage: firmware

- Change: create-firmware-stage
- Files: firmware/pins.h, firmware/led_pwm.h, firmware/led_pwm.c, firmware/main.c, firmware/Makefile, firmware/DEVPLAN.md, docs/CHANGELOG.md, docs/DECISIONS.md
- Verification: ERC clean, DRC clean

## 2026-09-21: create pipeline stage: firmware

- Change: create-firmware-stage
- Files: firmware/pins.h, firmware/led_pwm.h, firmware/led_pwm.c, firmware/main.c, firmware/Makefile, firmware/DEVPLAN.md, docs/CHANGELOG.md, docs/DECISIONS.md
- Verification: pin mapping traced to docs/PINOUT.md; AVR toolchain execution was unavailable, so firmware/DEVPLAN.md explicitly records `not compiled here`; ERC, DRC, legibility, and documentation drift must remain clean.

## 2026-09-21: create pipeline stage: outputs

- Change: create-outputs-stage
- Files: outputs/, outputs/BOM.csv, docs/CHANGELOG.md, docs/DECISIONS.md
- Verification: ERC clean, DRC clean

## 2026-09-21: create pipeline stage: outputs

- Change: create-outputs-stage
- Files: outputs/, docs/CHANGELOG.md, docs/DECISIONS.md
- Verification: JLC Gerbers and drill, DXF and STEP outline, schematic and PCB SVG renders, and ordering BOM.csv must all export successfully; ERC, DRC, legibility, and documentation drift must remain clean.
- Release status: fabrication and ordering artifacts retain the documented draft-layout and UNVERIFIED-MPN limitations and are not release-authorized without specialist review.

## 2026-09-21: create pipeline stage: layout-draft

- Change: create-layout-draft-stage
- Files: quiet-orbit-qo-r1-usb-c-four-light-ambient-lamp-board.kicad_pcb, docs/LAYOUT.md, docs/CHANGELOG.md, docs/DECISIONS.md, quiet-orbit-qo-r1-usb-c-four-light-ambient-lamp-board.kicad_pro
- Verification: ERC clean, DRC clean

## 2026-09-21: create pipeline stage: layout-draft

- Change: create-layout-draft-stage
- Files: quiet-orbit-qo-r1-usb-c-four-light-ambient-lamp-board.kicad_pcb, quiet-orbit-qo-r1-usb-c-four-light-ambient-lamp-board.kicad_pro, docs/LAYOUT.md, docs/CHANGELOG.md, docs/DECISIONS.md
- Verification: exact placement coordinates recorded; routed power-entry nets require clean DRC; documentation drift required clean

Append-only, newest first. One entry per committed copperhead run.

## 2026-09-21: create pipeline stage: schematic

- Change: create-schematic-stage
- Files: schematic.intent.json, quiet-orbit-qo-r1-usb-c-four-light-ambient-lamp-board.kicad_sch, docs/SUBSYSTEMS.md, docs/PINOUT.md, docs/CHANGELOG.md, docs/DECISIONS.md
- Verification: ERC clean

## 2026-09-21: create pipeline stage: schematic

- Change: create-schematic-stage
- Files: schematic.intent.json, quiet-orbit-qo-r1-usb-c-four-light-ambient-lamp-board.kicad_sch, docs/PINOUT.md, docs/SUBSYSTEMS.md, docs/DECISIONS.md, docs/CHANGELOG.md
- Verification: canonical installed symbols and real pins checked; deterministic draft generated; ERC, legibility, and documentation drift required clean

## 2026-09-21: create pipeline stage: part-selection

- Change: create-part-selection-stage
- Files: docs/BOM.md, docs/CHANGELOG.md, docs/DECISIONS.md
- Verification: ERC not required

## 2026-09-21: create pipeline stage: part-selection

- Change: create-part-selection-stage
- Files: docs/BOM.md, docs/DECISIONS.md, docs/CHANGELOG.md
- Verification: installed KiCad symbols and package pins checked for every IC, connector, active/protection part, and test point; electrical budgets calculated; documentation drift check required

## 2026-09-21: create pipeline stage: architecture

- Change: create-architecture-stage
- Files: docs/SUBSYSTEMS.md, docs/CHANGELOG.md, docs/DECISIONS.md
- Verification: ERC not required

## 2026-09-21: create pipeline stage: architecture

- Change: create-architecture-stage
- Files: docs/SUBSYSTEMS.md, docs/DECISIONS.md, docs/CHANGELOG.md
- Verification: documentation drift check; ERC and DRC not required

## 2026-09-21: create pipeline stage: spec-seed

- Change: seed-qo-r1-spec
- Files: docs/SPEC.md, docs/DECISIONS.md
- Verification: ERC not required

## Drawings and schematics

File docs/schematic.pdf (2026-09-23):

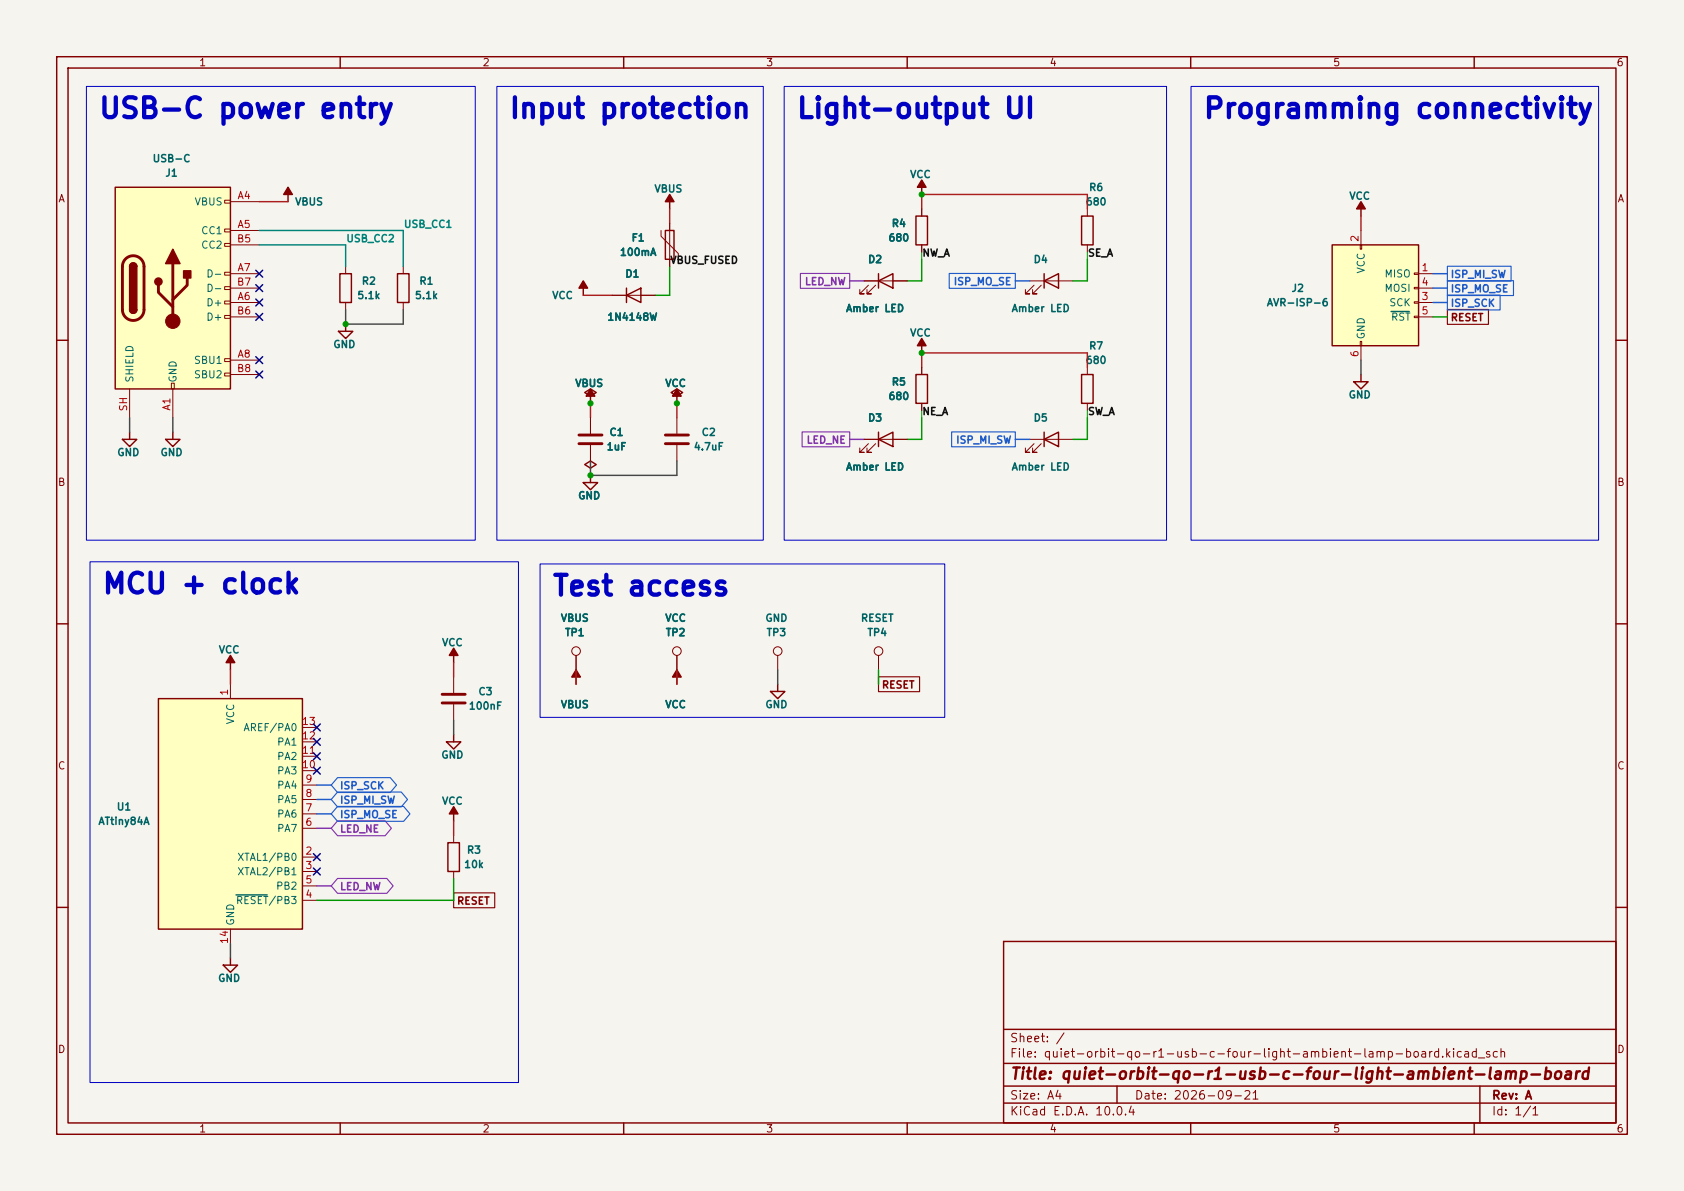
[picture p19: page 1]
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

Size: A4 | Rev: A
KiCad E.D.A. 10.0.4 | Id: 1/1

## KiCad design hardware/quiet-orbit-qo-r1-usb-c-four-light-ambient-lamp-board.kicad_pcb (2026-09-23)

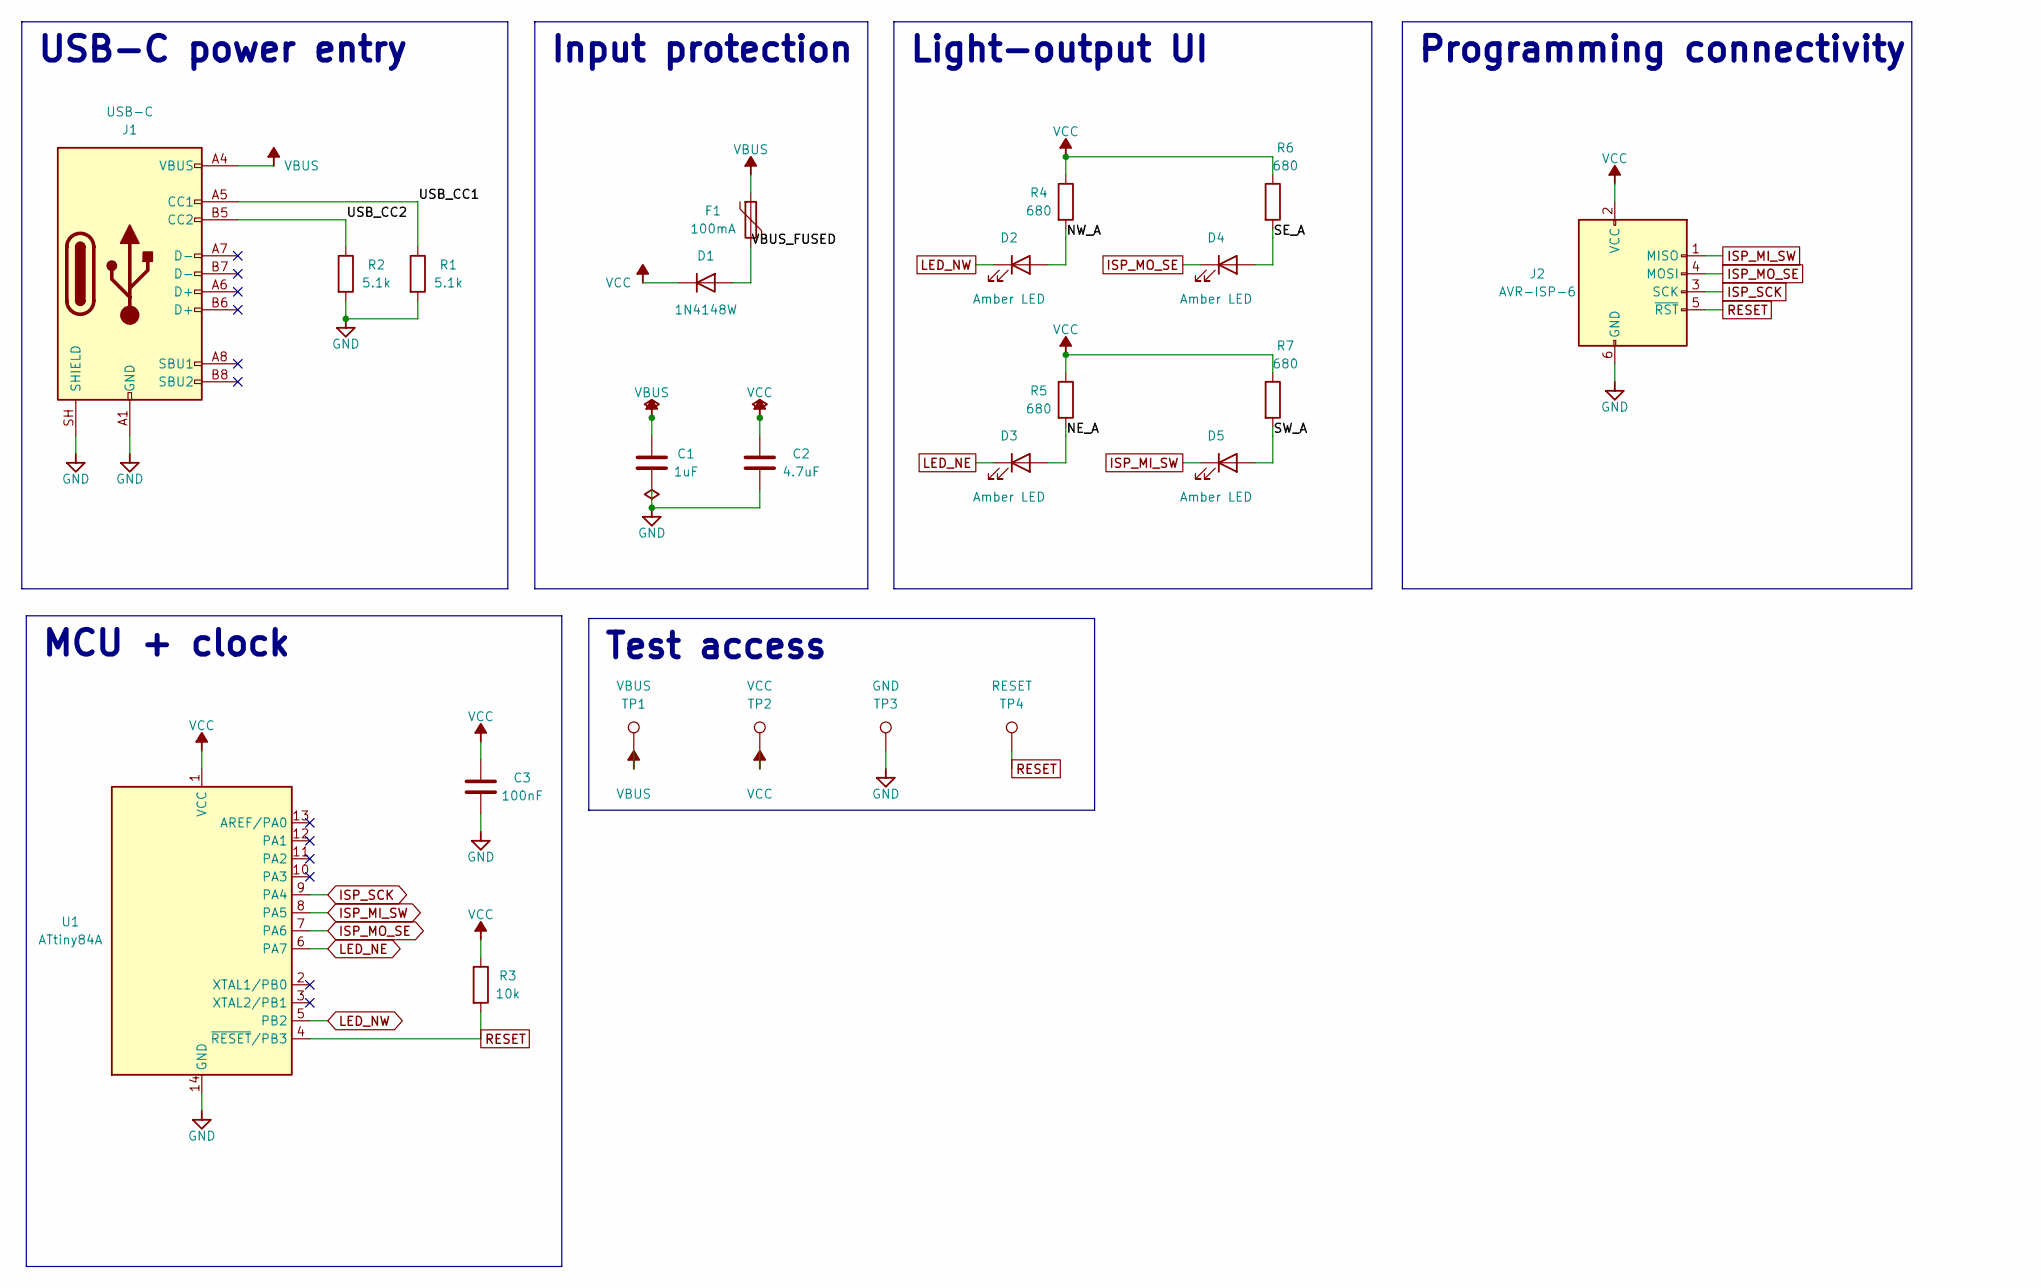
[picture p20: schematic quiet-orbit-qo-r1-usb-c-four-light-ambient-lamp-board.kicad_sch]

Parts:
C1: 1uF; C_0603_1608Metric
C2: 4.7uF; C_0805_2012Metric
C3: 100nF; C_0603_1608Metric
D1: 1N4148W; D_SOD-123
D2, D3, D4, D5: Amber LED; LED_1206_3216Metric
F1: 100mA; Fuse_0603_1608Metric
J1: USB-C; USB_C_Receptacle_GCT_USB4105-xx-A_16P_TopMnt_Horizontal
J2: AVR-ISP-6; IDC-Header_2x03_P2.54mm_Vertical
R1, R2: 5.1k; R_0603_1608Metric
R3: 10k; R_0603_1608Metric
R4, R5, R6, R7: 680; R_0603_1608Metric
TP1: VBUS; TestPoint_Pad_D1.5mm
TP2: VCC; TestPoint_Pad_D1.5mm
TP3: GND; TestPoint_Pad_D1.5mm
TP4: RESET; TestPoint_Pad_D1.5mm
U1: ATtiny84A; SOIC-14_3.9x8.7mm_P1.27mm

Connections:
/NE_A: D3.2 (A), R5.2
/NW_A: D2.2 (A), R4.2
/SE_A: D4.2 (A), R6.2
/SW_A: D5.2 (A), R7.2
/USB_CC1: J1.A5 (CC1), R1.1
/USB_CC2: J1.B5 (CC2), R2.1
/VBUS_FUSED: D1.2 (A), F1.2
GND: C1.2, C2.2, C3.2, J1.A1 (GND), J1.A12 (GND), J1.B1 (GND), J1.B12 (GND), J1.SH (SHIELD), J2.6 (GND), R1.2, R2.2, TP3.1, U1.14 (GND)
ISP_MI_SW: D5.1 (K), J2.1 (MISO), U1.8 (PA5)
ISP_MO_SE: D4.1 (K), J2.4 (MOSI), U1.7 (PA6)
ISP_SCK: J2.3 (SCK), U1.9 (PA4)
LED_NE: D3.1 (K), U1.6 (PA7)
LED_NW: D2.1 (K), U1.5 (PB2)
RESET: J2.5 (~RST), R3.2, TP4.1, U1.4 (~RESET/PB3)
VBUS: C1.1, F1.1, J1.A4 (VBUS), J1.A9 (VBUS), J1.B4 (VBUS), J1.B9 (VBUS), TP1.1
VCC: C2.1, C3.1, D1.1 (K), J2.2 (VCC), R3.1, R4.1, R5.1, R6.1, R7.1, TP2.1, U1.1 (VCC)

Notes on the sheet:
Programming connectivity
Input protection
Light-output UI
USB-C power entry
MCU + clock
Test access

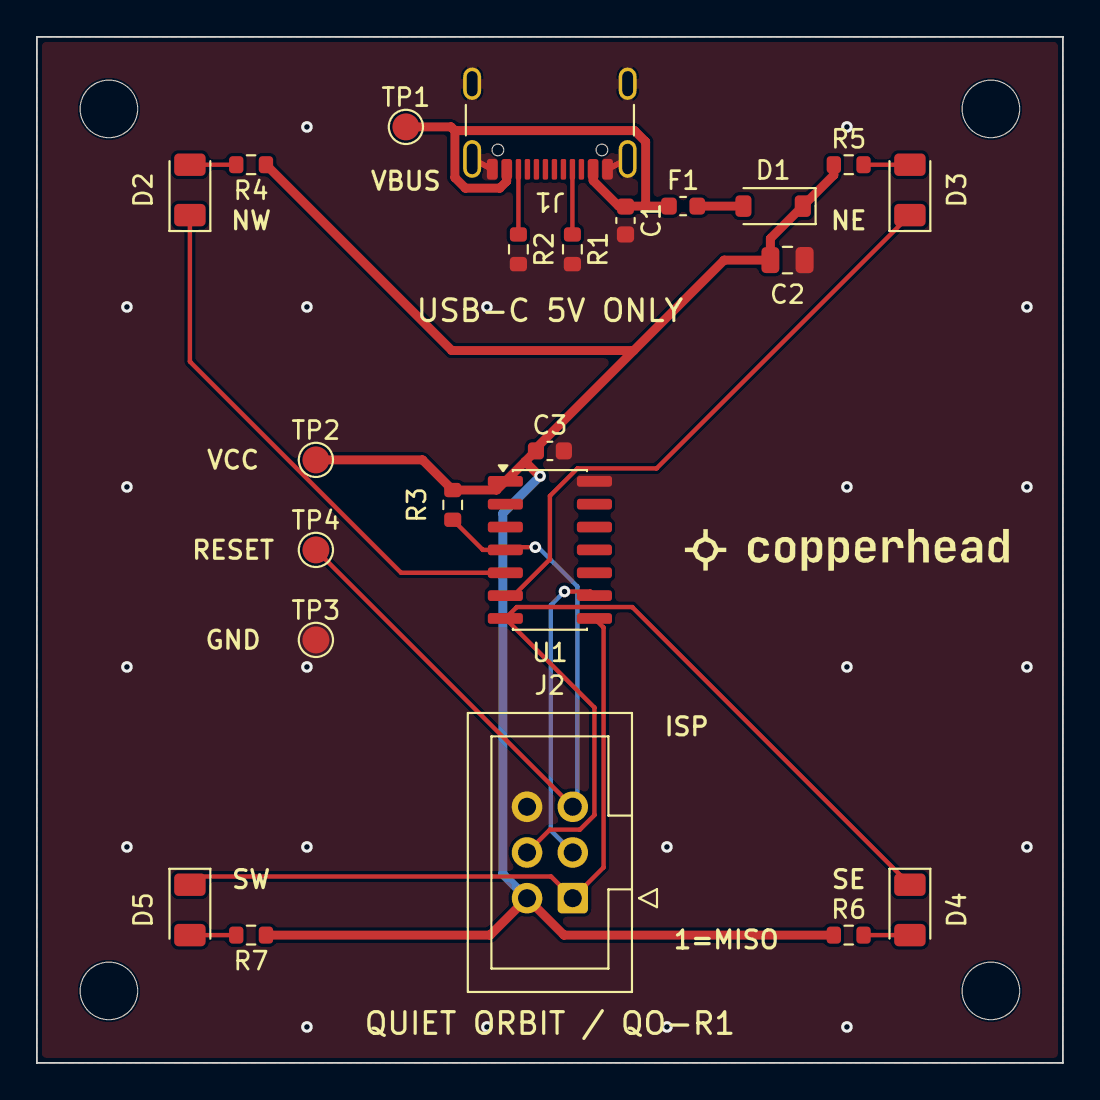
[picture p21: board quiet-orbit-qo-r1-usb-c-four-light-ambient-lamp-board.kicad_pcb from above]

Board: 2 copper layers, 57.0 x 57.0 mm, 27 parts (0 on the bottom side), 16 nets.

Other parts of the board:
H1, H2, H3, H4: M3; MountingHole_3.2mm_M3

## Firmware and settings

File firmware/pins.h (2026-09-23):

#ifndef QO_R1_PINS_H
#define QO_R1_PINS_H

#include <avr/io.h>

/* Generated from docs/PINOUT.md; do not assign board pins elsewhere. */
#define QO_MCU_PART                 ATtiny84A
#define QO_CPU_HZ                   8000000UL

/* U1.5: PB2 / OC0A, net LED_NW. */
#define LED_NW_DDR                  DDRB
#define LED_NW_PORT                 PORTB
#define LED_NW_BIT                  PB2
#define LED_NW_OCR                  OCR0A

/* U1.6: PA7 / OC0B, net LED_NE. */
#define LED_NE_DDR                  DDRA
#define LED_NE_PORT                 PORTA
#define LED_NE_BIT                  PA7
#define LED_NE_OCR                  OCR0B

/* U1.7: PA6 / MOSI / OC1A, net ISP_MO_SE. */
#define LED_SE_DDR                  DDRA
#define LED_SE_PORT                 PORTA
#define LED_SE_BIT                  PA6
#define LED_SE_OCR                  OCR1A
#define ISP_MOSI_DDR                DDRA
#define ISP_MOSI_PORT               PORTA
#define ISP_MOSI_BIT                PA6

/* U1.8: PA5 / MISO / OC1B, net ISP_MI_SW. */
#define LED_SW_DDR                  DDRA
#define LED_SW_PORT                 PORTA
#define LED_SW_BIT                  PA5
#define LED_SW_OCR                  OCR1B
#define ISP_MISO_DDR                DDRA
#define ISP_MISO_PORT               PORTA
#define ISP_MISO_BIT                PA5

/* U1.9: PA4 / SCK, net ISP_SCK. */
#define ISP_SCK_DDR                 DDRA
#define ISP_SCK_PORT                PORTA
#define ISP_SCK_BIT                 PA4

/* U1.4: PB3 / RESET, net RESET; fuse-controlled reset input. */
#define RESET_DDR                   DDRB
#define RESET_PORT                  PORTB
#define RESET_BIT                   PB3

/* U1.2, U1.3, U1.10-U1.13 are NC by design. */

#endif

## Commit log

2026-09-23 Quiet Orbit QO-R1: unbuilt reference design, 57 mm
    Schematic, board, firmware, fab outputs and renders. Never fabricated,
    never powered, firmware never compiled.
    [QO-R1-57mm-bom-jlcpcb.csv, quiet-orbit-57mm-board-only.stl, quiet-orbit-57mm-mechanical.step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]
2026-09-23 Docs: renders without background; schematic in summary
